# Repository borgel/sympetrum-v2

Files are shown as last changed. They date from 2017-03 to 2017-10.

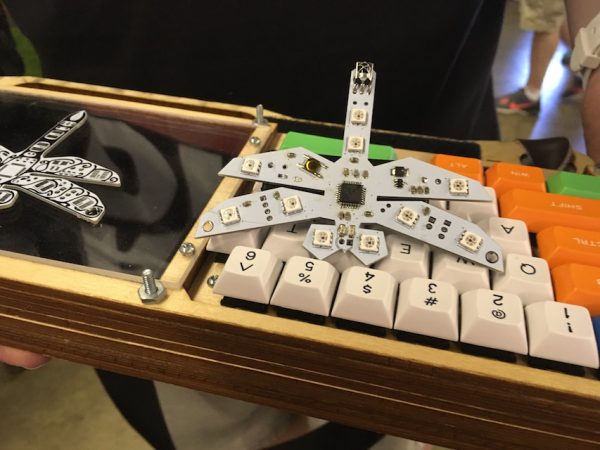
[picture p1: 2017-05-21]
Media/Adafruit commDeck_IMG_2102-600x450.jpeg

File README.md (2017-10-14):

# What?
An electronic conference badge, of course! (That makes this a wearable right?)

If you're interested in keeping up to date with new versions, you can add your email here: https://docs.google.com/forms/d/e/1FAIpQLSfi4PA6UNeILMCECjqM97Cd1tH6X2Ml2tzJlvIlYt14cOBuXQ/viewform. I'll start sending out info as we move towards DEFCON26.

## Yes, but what does it do?
By default the device does pleasant RGB fades across its 10 LEDs based on an internal clock. It also beacons that clock (and some other metadata) in infrared. They use any beacons they notice to synchronize their clocks, which also synchronizes the RGB patterns. The effect is that if one is alone, it plays random colors. If a group of them are together, they tend towards traversing the colorspace together.

For a little more information, it was kindly [written up by Hackaday here](https://hackaday.com/2017/07/14/badge-from-diamond-age-comes-to-def-con/).

This is a complete rewrite of the work done hastily in https://github.com/borgel/sympetrum for [DEFCON](https://defcon.org/) 24. The goal is to deploy at DEFCON 25 this year.

## Why is it a dragonfly?
If you haven't read Neal Stephenson's [_The Diamond Age: or, A Young Lady's Illustrated Primer_](http://www.goodreads.com/book/show/827.The_Diamond_Age), do that first. I'll wait.

If you have, there's a sequence around page 300 in which Miranda is first introduced to the possibility of using the drummers to find Nell. In this scene she attends a party in which the revellers wear colorful cloisonné dragonfly pins. As the party progresses they transition from random colorful flickering to some sort of synchrony, and Miranda notices the participants do the same. This is what I built.

A [_Sympetrum_](https://en.wikipedia.org/wiki/Sympetrum) is a genus of Dragonfly.

# How Do I Get One?
Unfortunately, I'm totally out. But everything is totally open source, so you can make one yourself! If you're interested check out [the Hardware Readme](Hardware/README.md) for recommendations.

The firmware used at DEFCON25 seems to work correctly and is considered "Final" barring bug discovery.

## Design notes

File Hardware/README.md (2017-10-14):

# Make One
If you're interested in making a Sympetrum badge, you're going to need two things: blank PCBs to assemble and the parts to assemble them with. Everything you'll need can be easily found on this project's [Kitnic page](https://kitnic.it/boards/github.com/borgel/sympetrum-v2/). 

## PCBs
Hit the button on the top of the Kitnic page that says "Download Gerbers". You'll get a zip file of the electrical files which describe the circuit board in a way that can be consumed by a fabrication house. There are a wide range of options for tuning these into circuit board you can use. Fab's I've purchased boards from and been happy include [PCBWay](https://www.pcbway.com), [Seeed Studio](https://www.seeedstudio.com/fusion_pcb.html) and [Dirty PCBs](https://dirtypcbs.com/store/pcbs). There are many other options. These boards are designed to fit in the common 100mm x 100mm size which is often heavily discounted. Expect these to cost around $25 (with shipping to the US!) for 10 in any color you want (they were designed for white solder mask / black silkscreen, the design should work correctly in any color).

### A Note on OSHPark
I love OSHPark and use them for all sorts of projects! Unfortunately for boards this large they are quite a bit more expensive than the Chinese options at around $60 for three boards. The quality will probably be higher but not likely in a meaningful way.

## Parts
The easiest way to order parts is again to use Kitnic. Below the images of the board there is a quantity selector and a Digikey button. If you press the button the webpage will magically open a Digikey card with all the parts in it (nifty isn't it?). At the time of writing it costs around $13 to build a single board from Digikey

If you'd rather do things the hard way you can directly upload the BOM to [Digikey](https://www.digikey.com/) or a tool like [Octopart](https://octopart.com/bom-tool) which will make it easy to order from a variety of suppliers.

### Caveats
* APA102C's, (AKA [DotStars on Adafruit](https://www.adafruit.com/product/2343)) may not be in stock on Digikey. If not, you can [buy them from Adafruit](https://www.adafruit.com/product/2343). You will need 10 for one dragonfly, though I recommend getting extra to fix ones that get damaged during assembly. They are also _much cheaper_ from EBay or Aliexpress, so consider those options if you're comfortable with them or  cost sensitive.
* The battery holder may not exactly fit the through holes on the PCB. They were custom sized to fit exactly the cheap holders I got on [Aliexpress](aliexpress.com). You could try lining one leg up and forcing the other to bend. Or use a holder with wires and gluing/taping it into place.

### Alternative Parts
Nothing in this design is particularly sensitive. If some specific part I selected is out of stock it should be safe to replace with a random part with the same parameters.

#### CPU
Sometimes the CPU seems to disappear from the common US suppliers. If this happens and you don't want to source from elsewhere the [STM32F051K8T6](https://www.digikey.com/product-detail/en/stmicroelectronics/STM32F051K8T6/497-13626-ND/3947378) can be swapped in place of the normal CPU. It's slightly fancier (AKA more expensive) and will require you to recompile the firmware for it, but that should be it.

To recompile the firmware for this CPU edit [the Makefile](/Firmware/Makefile) and swap the `CPU` variable by commenting out the line for `STM32F030x6` and in the one for `STM32F051x8`.

# Raw Sources
The final release gerbers are named `FF1.1` (formfactor 1.1) are [here](FF1.1). This is exactly what the Kitnic link mentioned above links to. This the final design which was used at DEFCON25.

The firmware is ["version 4"](https://github.com/borgel/sympetrum-v2/releases/tag/v4) and is tagged as a release on GitHub (and in [the Firmware directory](/Firmware)).

# Editiing/Contributing
If you want to make modifications, all design files made with [KiCAD](http://kicad-pcb.org/), a "Cross Platform and Open Source Electronics Design Automation Suite." It's very powerful, but has a steep learning curve.

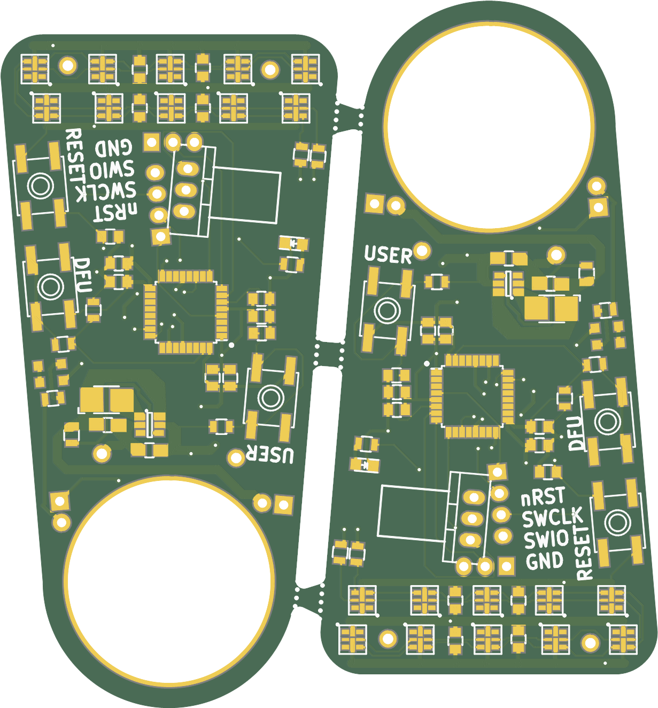
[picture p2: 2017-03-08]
Hardware/NFF1.1/gerbers-merged/merged-panel_Combined_Top.png

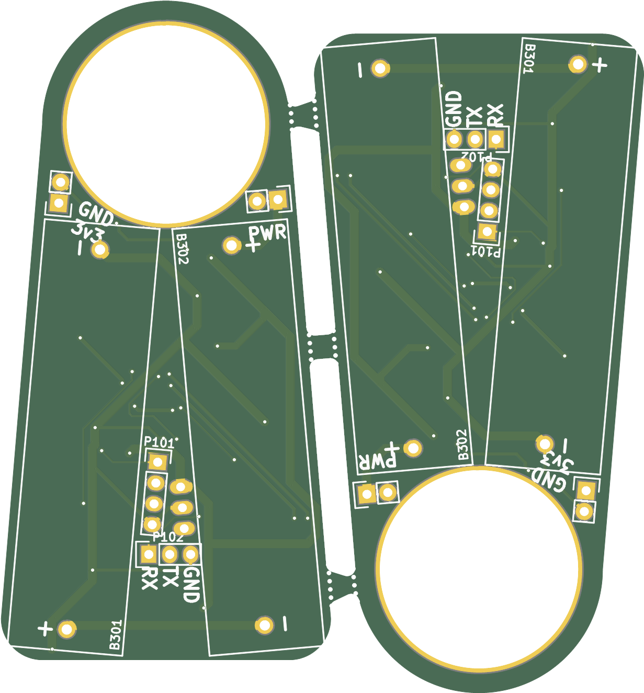
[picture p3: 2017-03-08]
Hardware/NFF1.1/gerbers-merged/merged-panel_Combined_Bottom.png

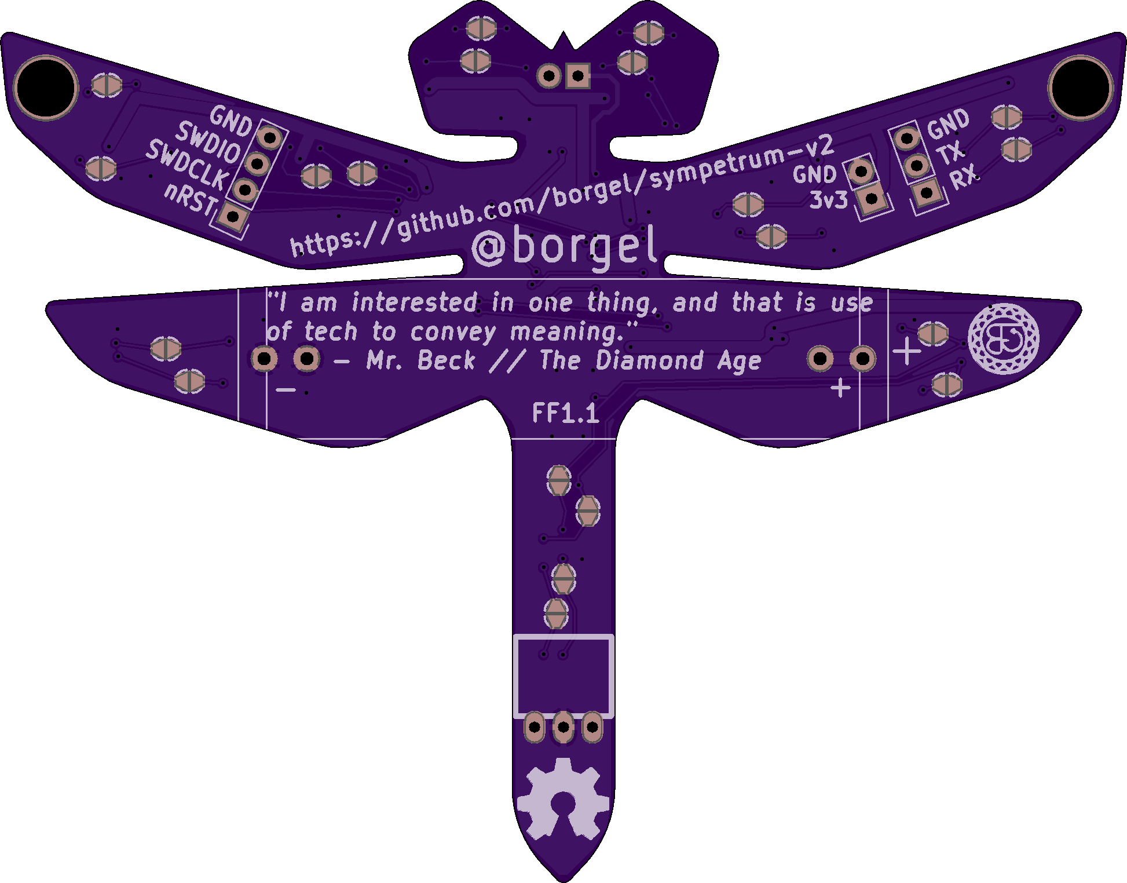
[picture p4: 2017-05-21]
Media/FF1.1 Back.png

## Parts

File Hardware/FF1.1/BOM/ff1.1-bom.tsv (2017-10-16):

References | Quantity | Description | PartNumber | DigiKey
U102 | 1 | TSSP58P38 | TSSP58P38 | TSSP58P38-ND
U101 | 1 | STM32F030K6T6 | STM32F030K6T6 | 497-14046-ND
U201;U202;U203;U204;U205;U206;U207;U208;U209;U210 | 1 | RGB LEDs | APA102C 5050 | 1528-1436-ND
B301 | 1 | AA Battery holder | BCAAPC | BCAAPC-ND
C101;C104;C105 | 3 | 0.1uF 0805 X7R |  | 478-3351-1-ND
C102 | 1 | 10nF 0805 X5R |  | 311-1136-1-ND
C103 | 1 | 1uF 0805 X5R |  | 1276-1246-1-ND
C202;C203;C201 | 3 | 22uF 0805 X5R |  | 1276-6460-1-ND
C106;C301;C302 | 3 | 4.7uF 0805 X5R |  | 1276-6465-1-ND
L301 | 1 | 4.7uH 0805 | LQH3NPN4R7NJ0L | 490-5346-1-ND
D102;D103 | 2 | IR25-21C/TR8 | IR25-21C/TR8 | 1080-1356-1-ND
R102 | 1 | 0R 0805 | RC0805JR-070RL | 311-0.0ARCT-ND
R101 | 1 | 10k 0805 |  | RMCF0805FT10K0CT-ND
R301 | 1 | 1M 0805 |  | RMCF0805JT1M00CT-ND
R103 | 1 | 36R 0805 |  | 311-36ARCT-ND
U301 | 1 | AAT1217-3.3 | AAT1217ICA-3.3-T1 | 863-1496-1-ND

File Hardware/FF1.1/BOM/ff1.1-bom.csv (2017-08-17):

Qty/Board | Line Item | Ref Des | Description | Manufacturer | MPN | DigiKey SKU | Distributor | Unit Price | Packaging | URL [Digi-Key]
1 | TSSP58P38 | U102 | TSSP58P38 | Vishay | TSSP58P38 | TSSP58P38-ND |  | 0.6615 | Bulk | https://octopart.com/click/track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
1 | STM32F030K6T6 | U101 | STM32F030K6T6 | STMicroelectronics | STM32F030K6T6 | 497-14046-ND |  | 1.0671 | Tray | https://octopart.com/click/track?country=US&ak=68b25f31&sig=009b28f&sid=459&ppid=30038872&ct=offers
10 | APA102C |  | RGB LEDs |  | APA102C 5050 | 1528-1436-ND |  |  | Bulk
1 | AA Holders |  | AA Battery holder |  | BCAAPC | BCAAPC-ND |  | 0.88 | Bulk | https://www.digikey.com/products/en?keywords=BCAAPC-ND%20
2 | 08055C104KAT2A | C104;C105 | 100nF |  | 08055C104KAT2A | 478-1395-1-ND | Digi-Key |  | Cut Tape
1 | 08055C104KAT2A | C101 | 0.1uF |  | 08055C104KAT2A | 478-1395-1-ND | Digi-Key |  | Cut Tape
1 | CC0805KRX7R9BB103 | C102 | 10nF | Yageo | CC0805KRX7R9BB103 | 311-1136-1-ND | Digi-Key | 0.0145 | Cut Tape | https://octopart.com/click/track?country=US&ak=68b25f31&sig=04411b9&sid=459&ppid=192989&ct=offers
1 | CC0805KKX7R7BB105 | C103 | 1uF | Yageo | CC0805KKX7R7BB105 | 311-1365-1-ND | Digi-Key | 0.0325 | Cut Tape | https://octopart.com/click/track?country=US&ak=68b25f31&sig=0ad85ca&sid=459&ppid=8376555&ct=offers
3 | CL21A226MQQNNNG | C202;C203;C201 | 22uF | Samsung | CL21A226MQQNNNG | 1276-6460-1-ND | Digi-Key |  | Cut Tape
3 | CL21F475ZPFNNNE | C106;C301;C302 | 4.7uF | Samsung | CL21F475ZPFNNNE | 1276-3022-1-ND | Digi-Key |  | Cut Tape | https://www.digikey.com/product-detail/en/samsung-electro-mechanics-america-inc/CL21F475ZPFNNNE/1276-3022-1-ND/3891108
1 | LQH3NPN4R7NJ0L | L301 | 4.7uH | Murata | LQH3NPN4R7NJ0L | 490-5346-1-ND | Digi-Key | 0.2646 | Cut Tape | https://octopart.com/click/track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
2 | IR25-21C/TR8 | D102;D103 | IR25-21C/TR8 | Everlight | IR25-21C/TR8 | 1080-1356-1-ND | Digi-Key | 0.1797 | Cut Tape | https://octopart.com/click/track?country=US&ak=68b25f31&sig=0198f6b&sid=459&ppid=17677898&ct=offers
1 | RC0805JR-070RL | R102 | 0R | Yageo | RC0805JR-070RL | 311-0.0ARCT-ND | Digi-Key | 0.0072 | Cut Tape | https://octopart.com/click/track?country=US&ak=68b25f31&sig=0bc70cf&sid=459&ppid=55402891&ct=offers
1 | RC0805JR-0710KL | R101 | 10k | Yageo | RC0805JR-0710KL | 311-10KARCT-ND | Digi-Key |  | Cut Tape
1 | RC0805FR-071ML | R301 | 1M | Yageo | RC0805FR-071ML | 311-1.00MCRCT-ND | Digi-Key | 0.0077 | Cut Tape | https://octopart.com/click/track?country=US&ak=68b25f31&sig=00e7688&sid=459&ppid=39987041&ct=offers
1 | RC0805FR-0736RL | R103 | 36R | Yageo | RC0805FR-0736RL | 311-36.0CRCT-ND | Digi-Key | 0.0077 | Cut Tape | https://octopart.com/click/track?country=US&ak=68b25f31&sig=09cc5c1&sid=459&ppid=1165961&ct=offers
1 | AAT1217ICA-3.3-T1 | U301 | AAT1217-3.3 | Skyworks Solutions | AAT1217ICA-3.3-T1 | 863-1496-1-ND | Digi-Key | 0.6774 | Cut Tape | https://octopart.com/click/track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

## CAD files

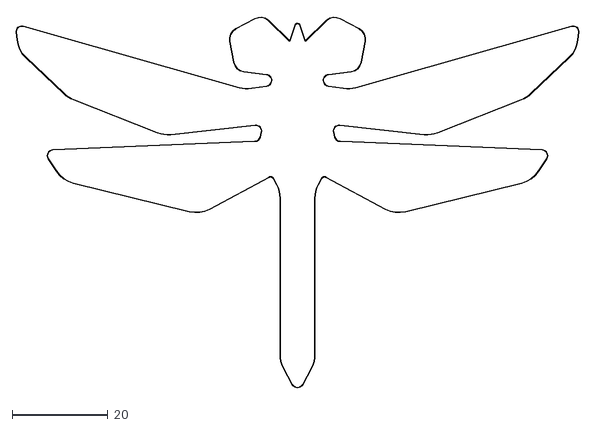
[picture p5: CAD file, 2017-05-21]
Hardware/FF1.1/Outline/Outline-Rounded-Libre-R12-v1 (Smaller).dxf
117.6 x 77.6

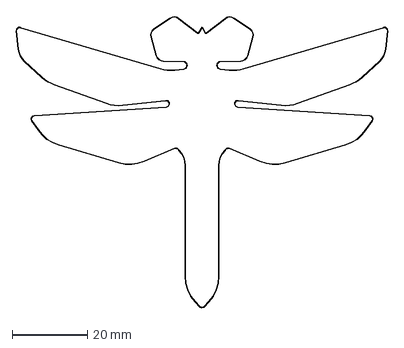
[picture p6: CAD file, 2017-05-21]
Hardware/FF1.1/Outline/Outline-Rounded-Libre.dxf
98.8 x 77.5 mm

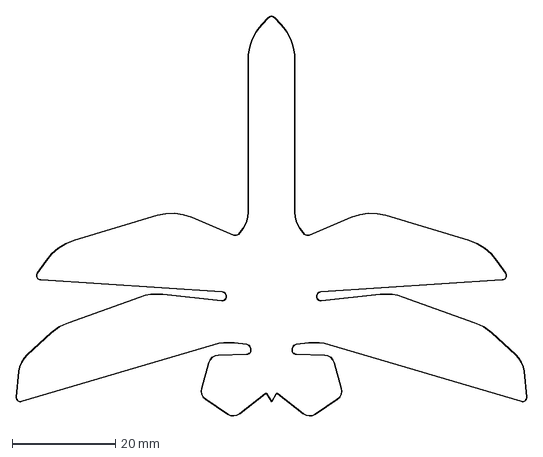
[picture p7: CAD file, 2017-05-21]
Hardware/FF1.1/Outline/Outline-Rounded-Fusion.dxf
98.8 x 77.5 mm

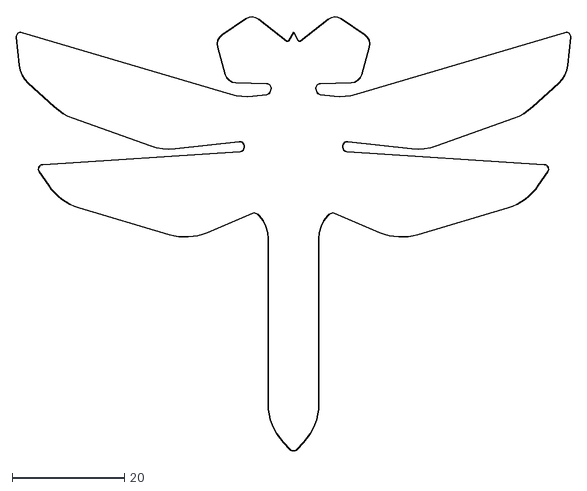
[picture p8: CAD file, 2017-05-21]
Hardware/FF1.1/Outline/Outline-Rounded-Libre-R12.dxf
98.8 x 77.5

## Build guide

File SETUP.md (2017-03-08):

# OSX
## CubeMX

A very handy GUI tool for confguring peripherals, clocktrees, etc. Can generate init code. Figuring out how to init peripherals in ST land can be _murderous_, so I recommend trying to use the tool.

1. Download [STM32 Cube MX](http://www.st.com/content/st_com/en/products/development-tools/software-development-tools/stm32-software-development-tools/stm32-configurators-and-code-generators/st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) from ST.

2. Install it. This will REQURE a version of the JRE and JDK (1.8 at time of writing). You MUST install these from the Oracle website [1] before the CubeMX installer will run.

3. Run the CubeMX installer. By default it installs a `/Applications/STMicroelectronics/STM32CubeMX.app`.

4. Run CubeMX and start a new project to configure a board.

5. When running the code generator, you will be asked to choose a toolchain. Unfortunately none of the options are "gcc" or similar. I've heard it recommended to select TrueStudio to generate our linker script for us. We will also need to manually construct a `makefile`.

### Notes

* The first time you run the code generator, it will notice you're missing the STM32Cube libraries themselves and offer to download them. Do this.
* There is a tool to generate Makefiles from CubeMX projects [6], but I was unable to get it to work. (However I did end up using their makefile as a template).

## Toolchain

1. Install the latest GNU Embedded Toolchain with `brew cask install gcc-arm-embedded`

2. Alternativel install latest GNU Embedded Toolchain for ARM from [3]. One recommendation for this is to do

```
$ mkdir -p /usr/local
$ cd /usr/local
$ sudo tar xjf ~/Downloads/gcc-arm-none-eabi-4_9-2015q3-20150921-mac.tar.bz2
```

3. Install the programming tools via Homebrew (or from source[4]) `brew install stlink`. A small tutorial for using these tools to flash a board is at [5].

## Building

1. TODO explain how to adapt my Makefile.

## Flashing

1. TODO. Explain how to call `st-flash write FILENAME.bin 0x8000000` and what each param means.

# Other Platforms

For Windows and Linux, apparently there is now a free (not open source?) Eclipse-based IDE for STM32 [2].

[1] http://www.oracle.com/technetwork/java/javase/downloads/jdk8-downloads-2133151.html http://www.oracle.com/technetwork/java/javase/downloads/jre8-downloads-2133155.html
[2] http://www.st.com/en/development-tools/sw4stm32.html http://www.openstm32.org/HomePage
[3] https://developer.arm.com/open-source/gnu-toolchain/gnu-rm/downloads
[4] https://github.com/texane/stlink
[5] https://github.com/texane/stlink/blob/master/doc/tutorial.md
[6] https://github.com/baoshi/CubeMX2Makefile

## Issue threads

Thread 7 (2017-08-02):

Generic Parts Listed

gh0stshell, 2017-08-02:
I need help identifying the parts listed as generic on your BOM located at

https://upverter.com/borgel/748d5ee8f0eb00f8/sympetrum-v02/

I dont know what parts I need to get

borgel, 2017-08-03:
Hmm, you might not want to build that version. It's harder to assemble and the FW never worked quite right. If you're trying to make the version from this year you want the files in the 'Hardware/FF1.1" directory in this repo. I'm still putting together a BOM to make it easy to buy parts though (hopefully done in the next few days).

gh0stshell, 2017-08-03:
What is the dimensions? One site I am getting a price for the board requires PCB Dimension.

borgel, 2017-08-04:
Boards are slightly less than 10cm x 10cm (if you're ordering from a place with size buckets).

Not sure if it's helpful yet, but I got a basic BOM up https://github.com/borgel/sympetrum-v2/tree/master/Hardware/FF1.1/BOM

gh0stshell, 2017-08-04:
Looks good, no generic parts listed

gh0stshell, 2017-08-05:
Having an issue with this components

CL21A106KQCLRNC

Would either of this work as a alt?

CC0402KRX5R6BB104

SMD CAP Ceramic 100nF-10V-10%-X5R

gh0stshell, 2017-08-05:
Actually the part on the sheet CL21A106KQCLRNC lists 100nF, but when you check the link it lists

CAP CER 10UF 6.3V X5R 0805

So how about this one?

CC0402MRX5R5BB106

gh0stshell, 2017-08-05:
Also for the APA102C

How about this one? WS2812B Adafruit is sold out of the APA102C atm

borgel, 2017-08-06:
Will check the passives when I get home. This design isn't very sensitive to tolerance and whatnot. As generally anything with the right value and the right size (everything is 0805) it should work.

Unfortunately you definitely cannot substitute the LEDs. The WS2812Bs communicate in a different way (and have 2 fewer pins!) So they won't work at all. However you can get APA102Cs from eBay and AliExpress pretty easily (usually much cheaper). You can also get non RGB versions which should work correctly, but obviously won't be color.

gh0stshell, 2017-08-06:
Ya I stuck with the listed LEDs and was able to find them even though adafruit was out of stock and bought some

gh0stshell, 2017-08-14:
7 and 11 show same PN, but difference decscrptions and price, I already started a full run of built units and boards, if I ordered the wrong parts per the links for 7 and 11 I can live with that, if the listings are wrong it will cost more of the pre-built units current being made

gh0stshell, 2017-08-14:
7 and 11 also show the same SKU as well

borgel, 2017-08-15:
Aww darn, no those should have different part numbers. Going to have to flog KiCAD and figure out what it should actually be. The value in the `Description` field looks like it's correct, so it's just the part number.

borgel, 2017-08-15:
Ok. It was actually supposed to be another `CL21A106KQCLRNC` like line 6 (yes, I labeled components with the same value in different units. Need to fix that too, but haven't changed the schematics to match it).

gh0stshell, 2017-08-15:
So what all is wrong now? This means the fully built boards have 3 wrong parts and I ordered incorrect parts and did not order.

borgel, 2017-08-16:
Crap. Well, it looks like 11 is still wrong. So so far my two errors look like lines 7 and 11.

7: Installing a different capacitor for 7 shouldn't matter (it just debounces the reset line. A bigger or smaller cap likely won't change anything).
11: This actually needs to be correct, and it looks like I have the wrong part number here too. I updated the BOM with the right part.

So it seems like just 11 needs to be fixed.

Sigh, I'm really sorry about this. I'm not sure at what step this got garbled... It's possible this happened earlier and I produced some amount of units with these errors

gh0stshell, 2017-08-16:
Actually no need to be sorry as I just got a response from the company and they have not gone to assembly yet so I have time send a correct BOM or what needs to be correct, if you could do that I it would be awesome

gh0stshell, 2017-08-16:
i see there is a new BOM, is that a correct one I can send for assembly?

borgel, 2017-08-17:
Awesome! Glad that was in time.

It's correct as far as I know, but I was wrong before... I'm still at work, but so far it looks like all the values in `Description` have been correct so far, but the part numbers haven't been. If you search for each part number and validate that it matches the `Description` that should catch anything left that's incorrect.

Out of curiosity, who are you having make/assemble the boards? What prices are you seeing? If you don't mind sharing.

borgel, 2017-08-17:
Turned out I had a little time. This is what I see wrong:
- It looks like `CL21A106KQCLRNC` is still wrong and matches neither line 6 or 7.
- 10 (CL21F105ZOFNNNE) is wrong
- 15 (RC0805JR-071KL) is wrong

All those have correct values... but not for that line. I wonder if somehow there was a bizarre reordering or something

Try making:
6: 08055C104KAT2A (DigiKey 478-1395-1-ND)
7: 08055C104KAT2A (DigiKey 478-1395-1-ND)
10: CL21A226MQQNNNG (DigiKey 1276-6460-1-ND)
15: RC0805JR-0710KL (DigiKey 311-10KARCT-ND)

borgel, 2017-08-17:
Ok, I updated the BOM again. I've now checked everything manually against its `Description` field and believe it all to be correct.

gh0stshell, 2017-08-17:
OK I will download it again and send it off before I run out of time, thank you very much

gh0stshell, 2017-08-19:
bad news, 6 and 7 are now the same

borgel, 2017-08-19:
I think that's actually correct. I accidentally named C101 using a different unit from C104 and C105.

gh0stshell, 2017-08-19:
whew!

Could provide a file where is shows what parts go where(numbers on board to match BOM Ref Des) like the ones you just mentioned, it only shows the LED numbers on the board thanks in advance!

gh0stshell, 2017-08-19:
I also got just the board made an are ordering parts but dont know where to put them

gh0stshell, 2017-08-19:
also if you could give me a guide to flash the firmware I would appreciate it

gh0stshell, 2017-08-22:
So I figured out where the LEDs go and the ST chip, but no idea where the other parts go

borgel, 2017-08-23:
Sorry, was out of town and not doing much computing

I added a new document called `sympetrum-v2 FF1.1-F.Fab.pdf` to the HW/FF1.1 directory. It shows where each component goes.

There are two ways to flash the firmware.
1) Use an SWD programmer (like an ST-LINK/V2, or a Segger JLink, or a Bus Pirate, or others) and connect to the 4 pin programming header. If you need to get a programmer the cheapest option is probably to get one of the skeezy cheap ST-LINK/V2 Mini clones like [0]. I used one (from another source) for most of my development and it was fine.
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
gh0stshell, 2017-08-26:
Question, i am finishing up my board and last piece i am doing is the IR recv on the tail, it looks like the spot for it is on the back of the board, shouldn't be on the front so it talks to the other badges I will eventually have so the LEDs sync?

borgel, 2017-08-26:
Hmm, it should be on the top. There isn't really much on the silkscreen besides a vertical line underneath where the body sits at the veeeeeery end of the tail.

If you insert it's legs through the top then fold it down with the window having outward that should work.

borgel, 2017-08-26:
Do you mind sending a photo when you finish? I'd love to see how it turned out. It's kind of blowing my mind that someone else made one!

gh0stshell, 2017-08-27:
Ya sure, I just have to do the main chip, batt, and IR, I ask about the IR as there is a spot on back that is a square looking like where it sits

gh0stshell, 2017-08-27:
tip I will be using I learned from the DC Darknet badge, pliers to bend the IR, makes a perfect 90 degree angle and lays flush on the board

gh0stshell, 2017-08-27:
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

I have enough to make 9 more

jthoel, 2017-08-27:
Nice work!  I've been following along the conversation. I picked up a
broken one at DefCon and am trying to repair it.  I'm going to order leds
(i got the wrong ones earlier) and then test the board.  Great to see it
working!

On Sat, Aug 26, 2017 at 8:45 PM, gh0stshell <notifications@github.com>
wrote:

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

gh0stshell, 2017-08-27:
I ordered boards then ordered all the parts, i made this from scratch

gh0stshell, 2017-08-27:
here is a better pic from the maker

https://lh6.googleusercontent.com/Apjwzfcd5rGi5Dd5XBWZZPZ3DFGu11GQ79bOFPmc_ytsunu4enYdPfqG0VfeWvRQLmdTbMKzPg=w2620

borgel, 2017-08-27:
Oh, I see what happened @gh0stshell ! That little box is where I hand wrote the serial numbers! Should probably have considered that it wasn't clear what it was actually _for_.

Awesome! Looks great!

Holler if you have any questions @jthoel !

gh0stshell, 2017-08-27:
I want to change the colors so I can use a different board color then white, what would I need to do that?

WildSamosa, 2017-08-27:
@gh0stshell I was able to order PCBs in white with black silkscreen, and black with white silkscreen.  I used the same files for both orders and they came out great.  Waiting for parts from the updated BOM before I can assemble it.  Yours looks fantastic!  Did you have anything pick and placed, or is that all hand soldered?
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

gh0stshell, 2017-08-27:
i think we know each other on discord, only one part changed on the BOM recently and I made one before I got it and so did another that went in with me and it works without the one new part

gh0stshell, 2017-08-27:
#2 just was completed so now I now I can see them sync

gh0stshell, 2017-08-27:
@WildSamosa, i am building them all by hand, no assembly

gh0stshell, 2017-08-27:
and number 3 is done, soon i will have enough to hang from my ceiling, learned a good trick and which tip to use for the chip that also seems to work well with all the other parts, more precise

gh0stshell, 2017-09-07:
@WildSamosa, could I buy some black boards off you? I have other colors coming, but not black.

gh0stshell, 2017-09-07:
@borgel, how can I donate to you?

borgel, 2017-09-09:
Haha, no donations required. That's why it's open source! Just learn from it and put the knowledge to use!

gh0stshell, 2017-09-14:
So I have been playing with the first 2 I made, 3rd I have some programming issues most likely due to bridged pins, but with the working 2 I have hung them from the ceiling pointed at each other and waiting for them to sync and they never do so could you give me a run down of what to expect?

borgel, 2017-09-20:
Cool!

So when each one is powered on, they should do a random RGB fade across all the LEDs. When a few of them are "near" each other (with no obstructions or other sources of modulated IR I'd think the range would be pretty far. 10 feet maybe? 15?) they will slowly switch from a random fade to a cycle through the RGB spectrum.

With the values in the last version of the firmware, two boards will appear to be partially random and partially "synced", and three boards will look nearly totally synced and not random at all. The more frequently they see a beacon from another board the less random they appear to be. It will likely take minutes for them to all line up. It's... a little hard to explain in text.

All this code lives in `pattern.c` [1]. To make two look fully synced instead of partially random, adjust the values in the array `BiasWeightRamp` in `pattern.c` so that each value is 90 or 100 (100 is the maximum).

[1] https://github.com/borgel/sympetrum-v2/blob/master/Firmware/Src/pattern.c

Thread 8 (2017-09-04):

Possibly missing libraries?

dodohand, 2017-09-04:
Opening sympetrum-v2 FF1.1.pro with KiCad 4.0.7-e2-6376-58-ubuntu14.04.1 and
I get errors that these two libraries weren't found:

"/Users/borgel/Dropbox/kicad/Libraries/Borgel Custom"
and
"/Users/borgel/Dropbox (Personal)/kicad/Libraries/Borgel Custom"

... and am then left with quite a mess of a schematic with lots of missing symbols.
Would it be possible for you to create a library of the symbols you've created for
this schematic and add it to this repo? (assuming this issues repeats for you when
you try it out on another machine without your Dropbox libraries?

gh0stshell, 2017-09-07:
looks like a known issue with linux and KiCad

Source: https://lists.launchpad.net/kicad-developers/msg25255.html
Repo Needed: sudo add-apt-repository --yes ppa:js-reynaud/kicad-4

I installed that version instead of the default on in the repo and no errors for me at least

gh0stshell, 2017-09-07:
Tried on my Win10 which looks like what is listed in your error and no errors out of the box for me at least

gh0stshell, 2017-09-07:
On the KiCad web site download section the PPA listed in the source I posted is also listed there under the ubuntu section

http://kicad-pcb.org/download/ubuntu/

borgel, 2017-09-07:
Thanks for catching that @dodohand ! (and for the help @gh0stshell ). It looks like I was missing a file.

I think my `.gitignore` quietly left off `sympetrum-v2 FF1.1-cache.lib`, which should be the library cache of all the symbols and things for the schematic. I just added it to `master`. Does it work now?

gh0stshell, 2017-09-07:
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

gh0stshell, 2017-09-07:
For me it keeps asking for 3 schem files, 2 you have posted, trying to see what the other one is

gh0stshell, 2017-09-07:
In Windows after adding .lib file I now get this when opening the schem file

The following libraries were not found:
sympetrum-v2 FF1.1-rescue
sympetrum-v2 FF1-rescue
\Users\borgel\Dropbox\kicad\Libraries\Borgel Custom
\Users\borgel\Dropbox (Personal)\kicad\Libraries\Borgel Custom

gh0stshell, 2017-09-07:
BUT it looks ok, i guess, im new to this so you guys tell me

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

gh0stshell, 2017-09-07:
So me wanting to not leave it alone, I copied sympetrum-v2 FF1.1-cache.lib, and made two copies named

sympetrum-v2 FF1.1-rescue.lib
sympetrum-v2 FF1-rescue.lib

And no oddness and those errors went away and now have these left

The following libraries were not found:
\Users\borgel\Dropbox\kicad\Libraries\Borgel Custom
\Users\borgel\Dropbox (Personal)\kicad\Libraries\Borgel Custom

dodohand, 2017-09-08:
I now get the same results as gh0stshell - namely that the schematic is now complete, but the footprints are unavailable. This means that while I can now, for example, correctly make a copy of U210 as U211 in order to add an 11th LED to the schematic, I cannot successfully import that netlist into Pcbnew because the footprint from ."../Libraries/Borgel Custom" is not available.  While I could create my own footprint, I think that you intended it to be self-contained, and it isn't yet.

borgel, 2017-09-09:
I'm really sorry about that, definitely still figuring out the best way to package all this up.

Based on [1], I archived all the footprints in the `.kicad_pcb`, then added that local footprint library to the project specific search path, then push it all up. Hopefully if you pull fresh from `master` it should work now.

[1] https://hackaday.com/2017/05/18/kicad-best-practises-library-management/

gh0stshell, 2017-09-10:
Tried on Windows this time, download the entire master, extracted it to a new folder, opened KiCad and pointed it to that folder and opened the pro file and when open sch

The following libraries were not found:
sympetrum-v2 FF1-rescue
\Users\borgel\Dropbox\kicad\Libraries\Borgel Custom
\Users\borgel\Dropbox (Personal)\kicad\Libraries\Borgel Custom

gh0stshell, 2017-09-10:
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

dodohand, 2017-09-26:
as gh0stshell demonstrated, the schematic now loads properly, and the footprints can be extracted from the pcb layout, so I'm going to close this.

Closed 2017-09-26.

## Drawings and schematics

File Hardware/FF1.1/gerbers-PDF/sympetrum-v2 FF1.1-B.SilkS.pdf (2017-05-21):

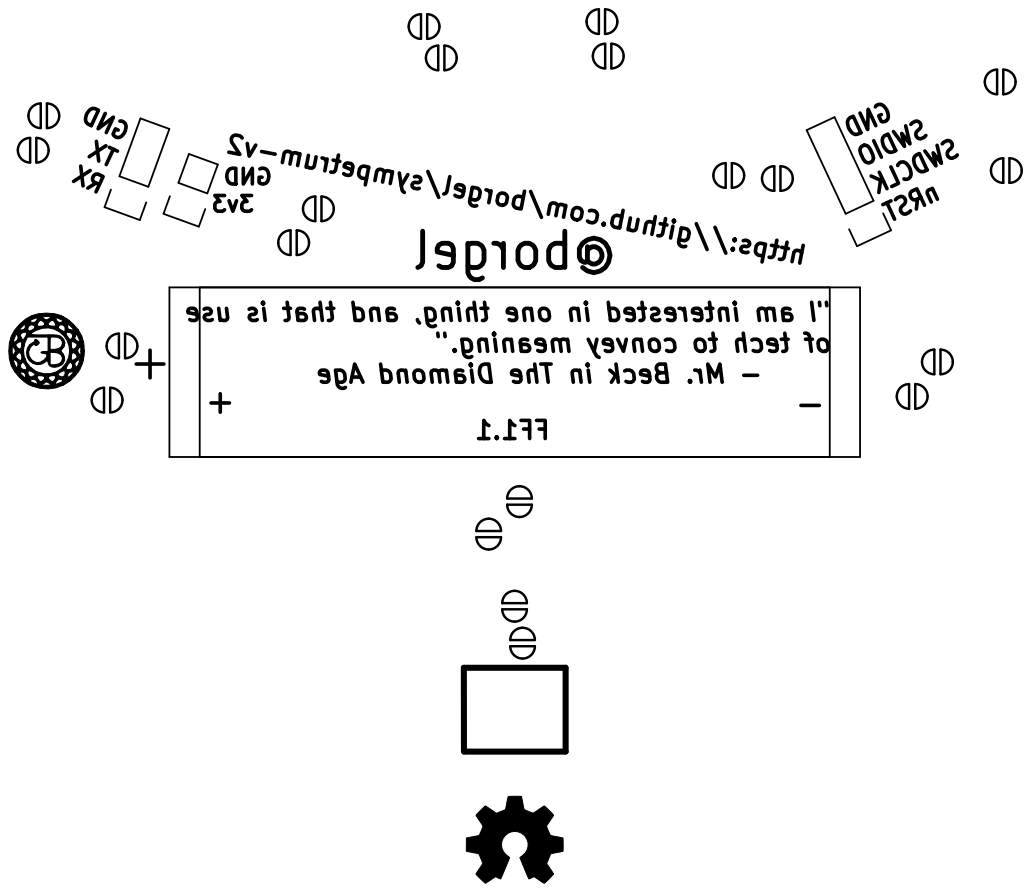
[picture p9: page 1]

GND TXRX https://github.com/borgel/sympetrum-v2

GND SWDIO SWDCLK nRST GND 3v3

"I am interested in one thing, and that is use

of tech to convey meaning." + - Mr. Beck in The Diamond Age

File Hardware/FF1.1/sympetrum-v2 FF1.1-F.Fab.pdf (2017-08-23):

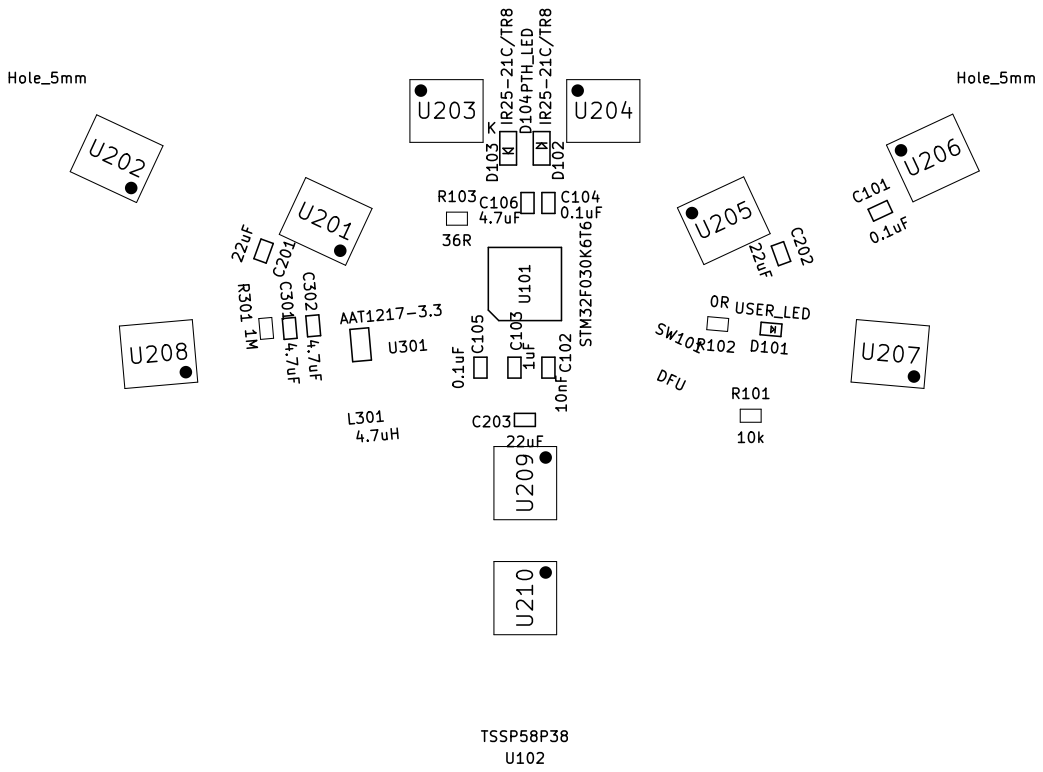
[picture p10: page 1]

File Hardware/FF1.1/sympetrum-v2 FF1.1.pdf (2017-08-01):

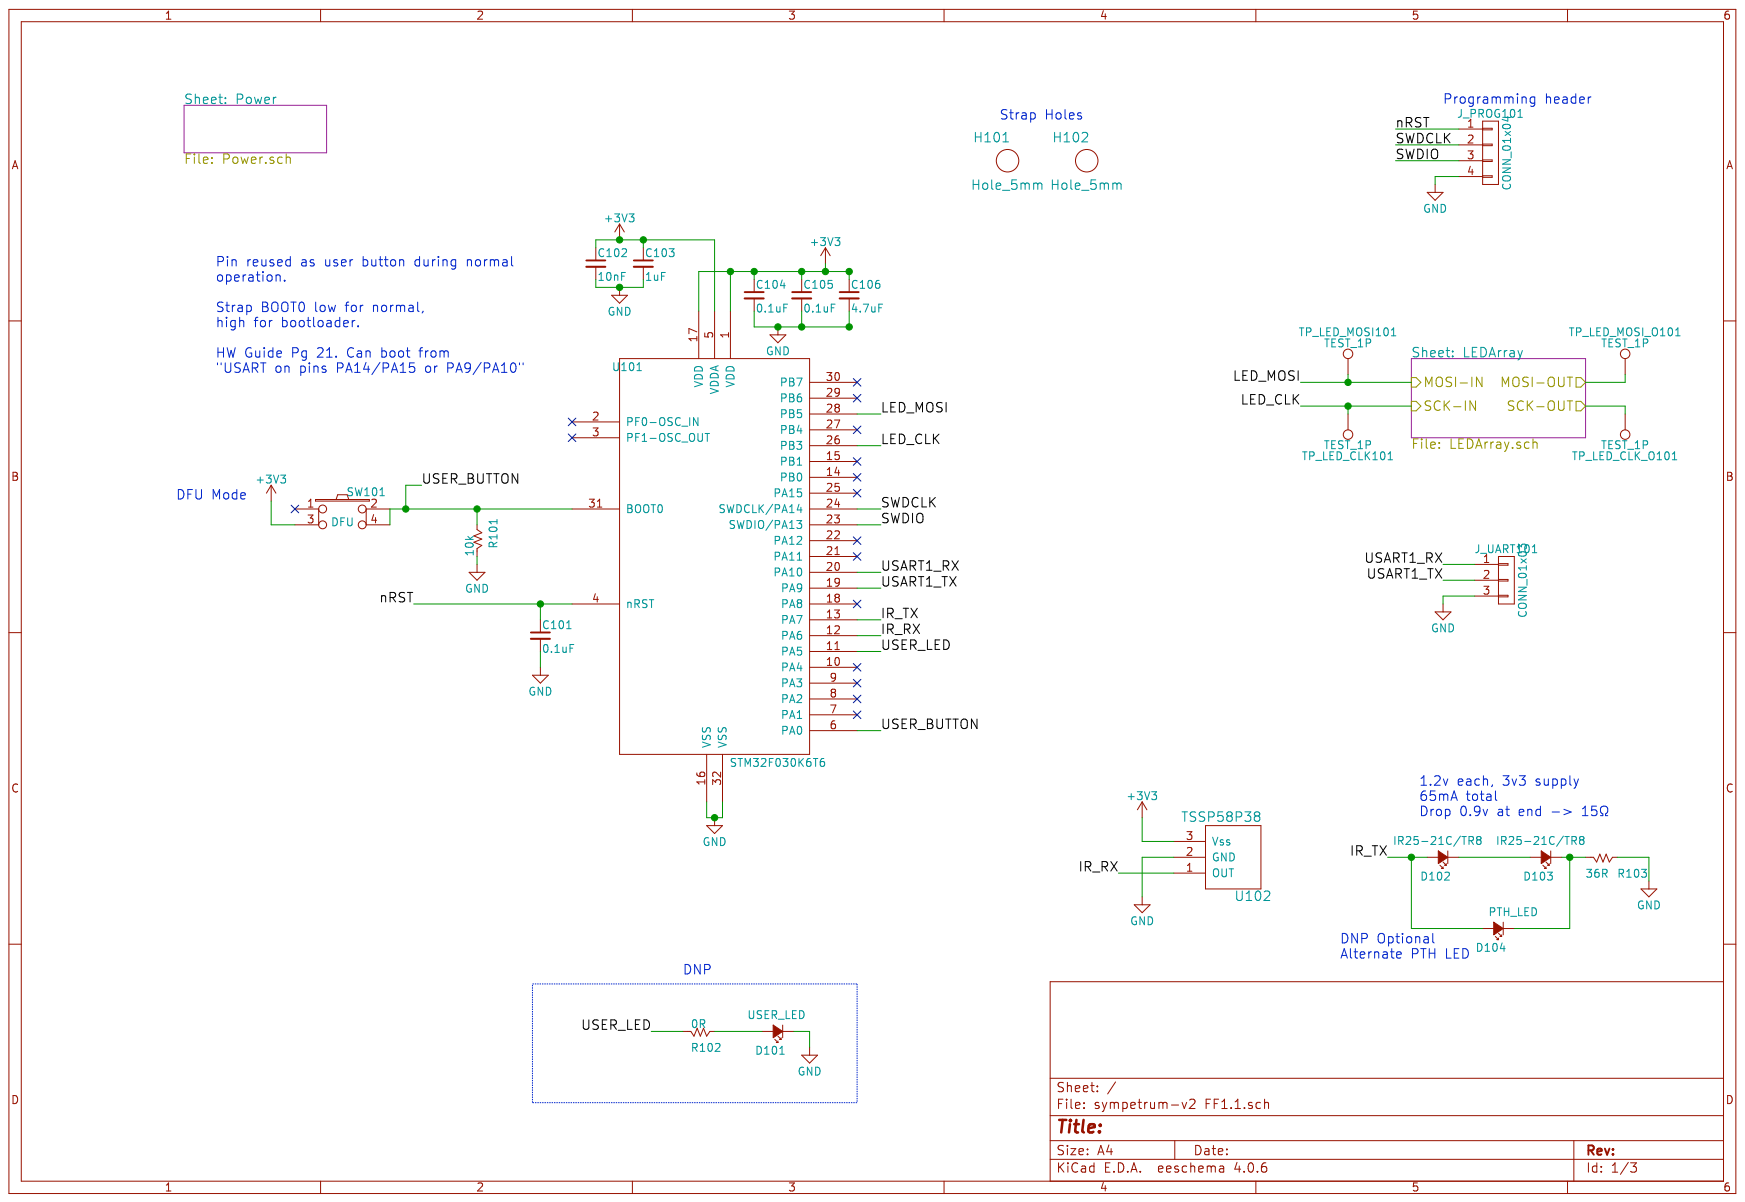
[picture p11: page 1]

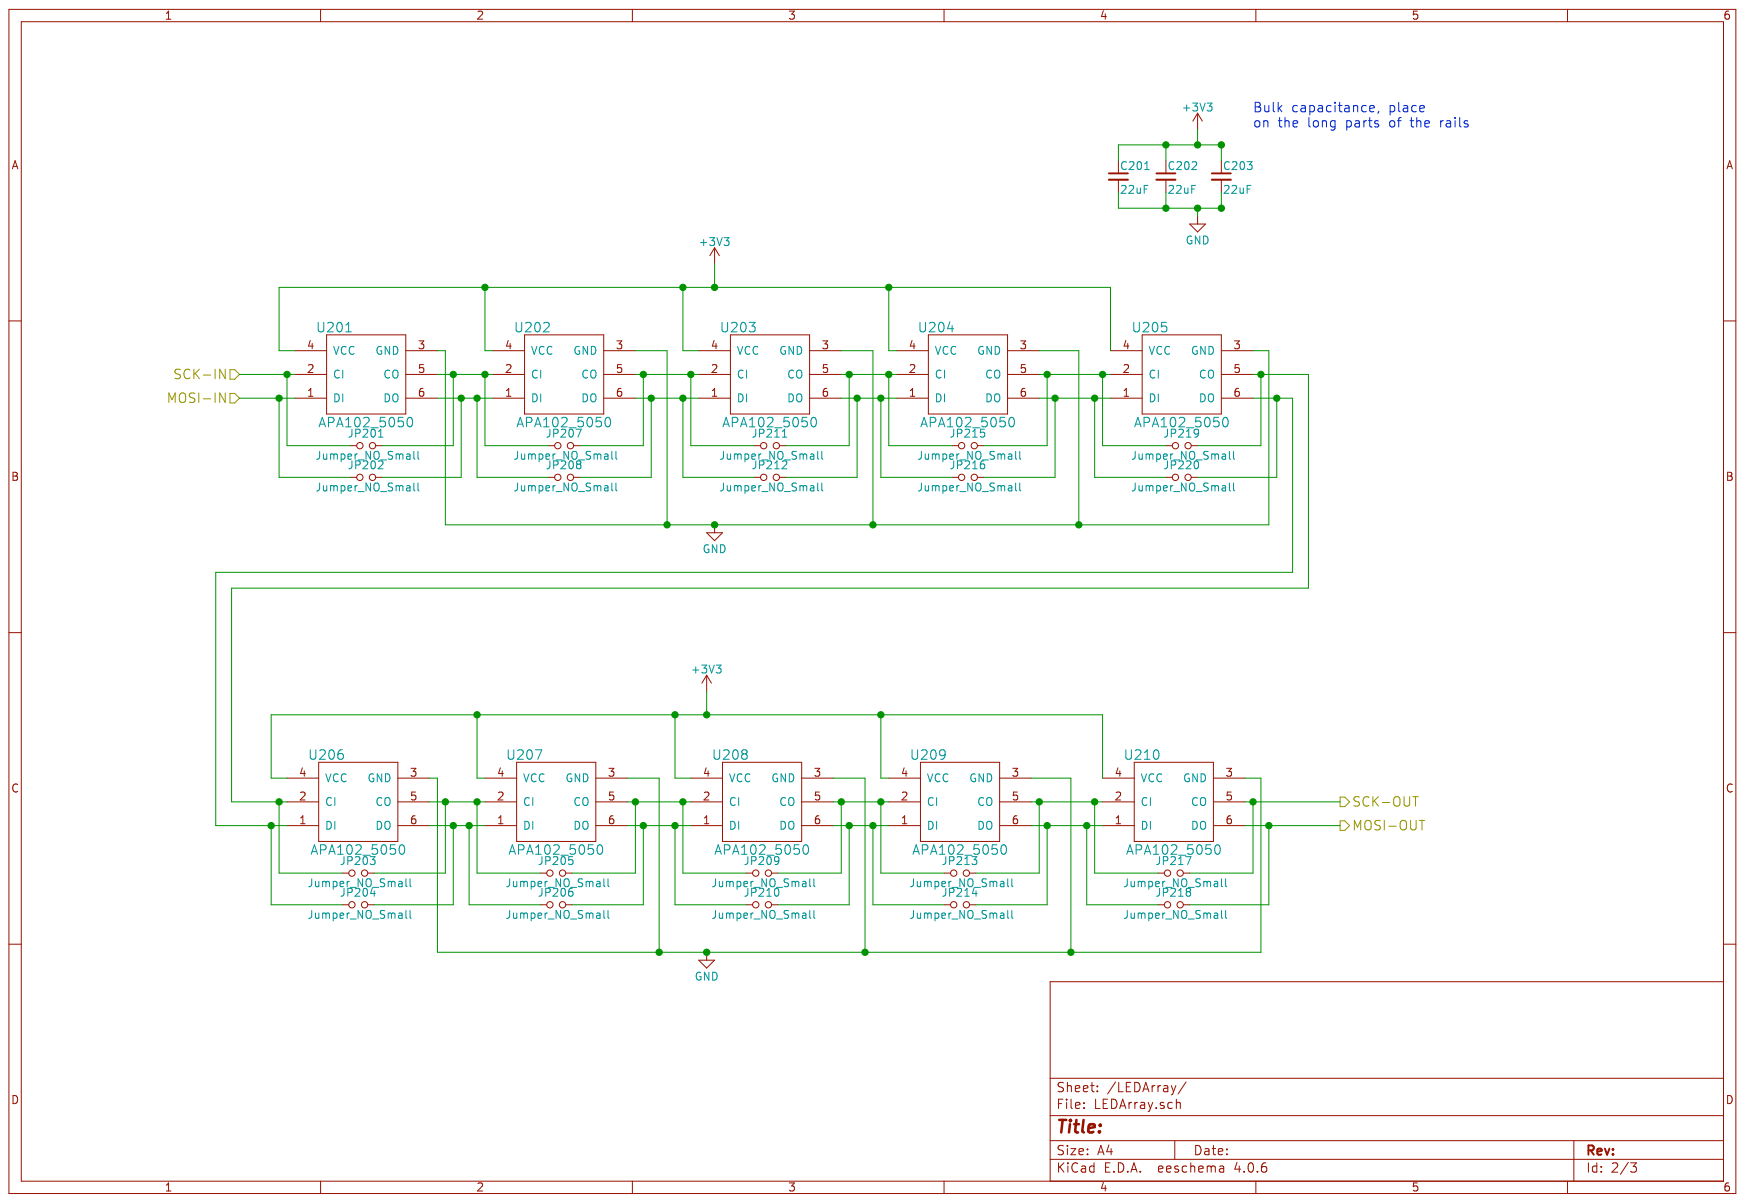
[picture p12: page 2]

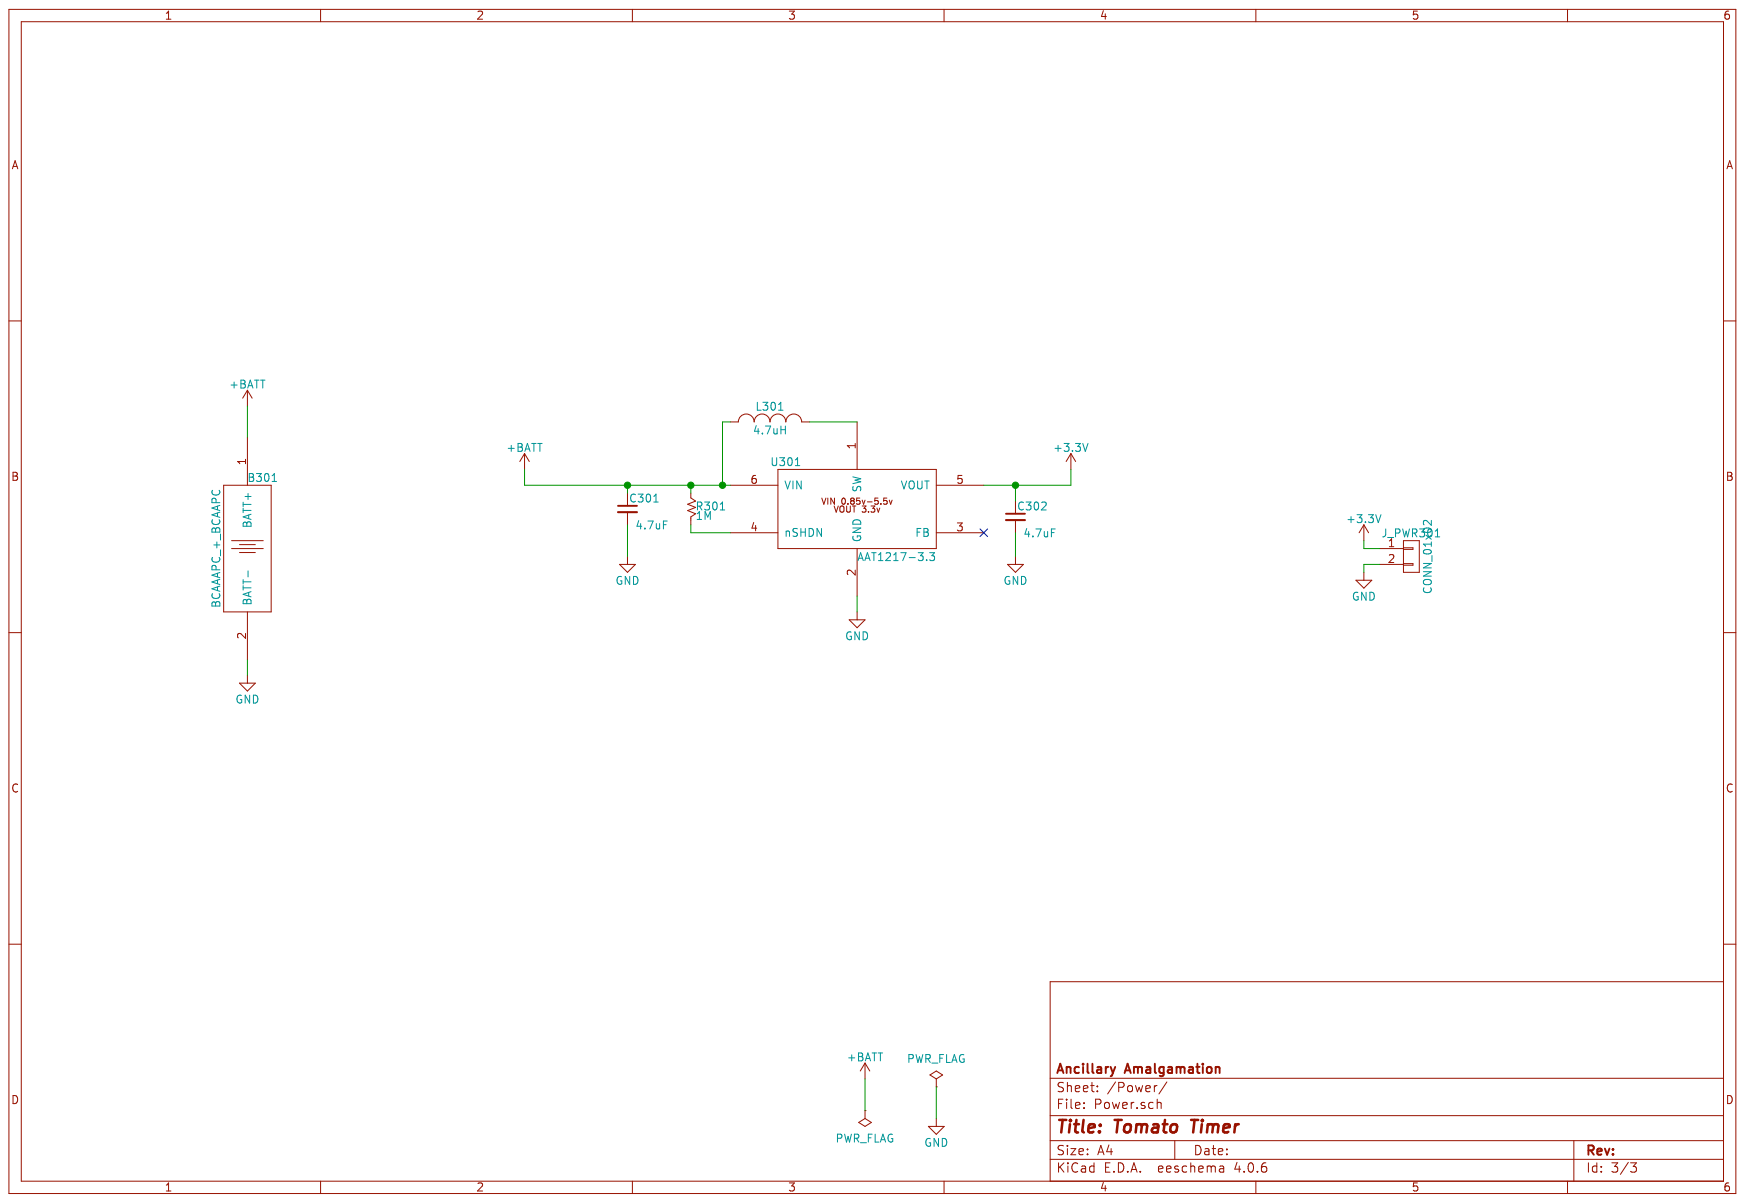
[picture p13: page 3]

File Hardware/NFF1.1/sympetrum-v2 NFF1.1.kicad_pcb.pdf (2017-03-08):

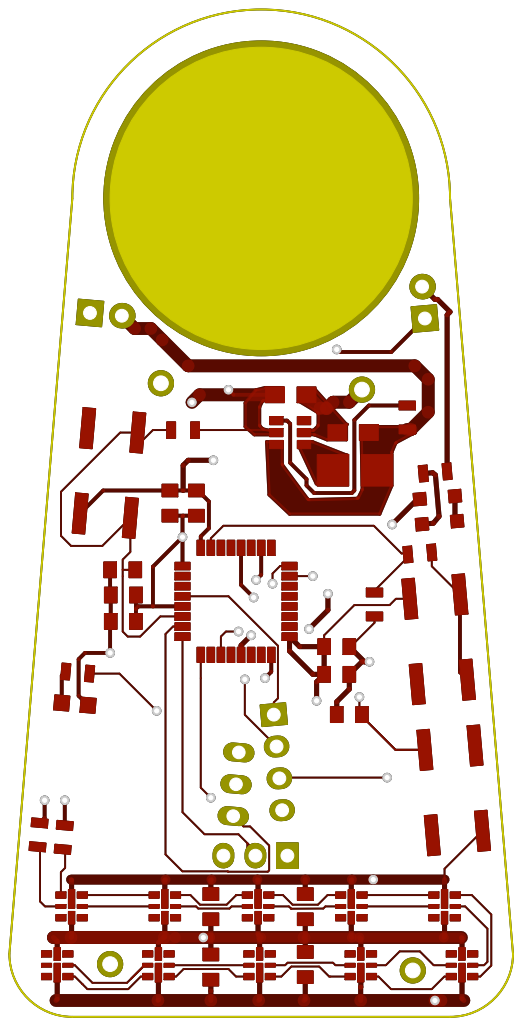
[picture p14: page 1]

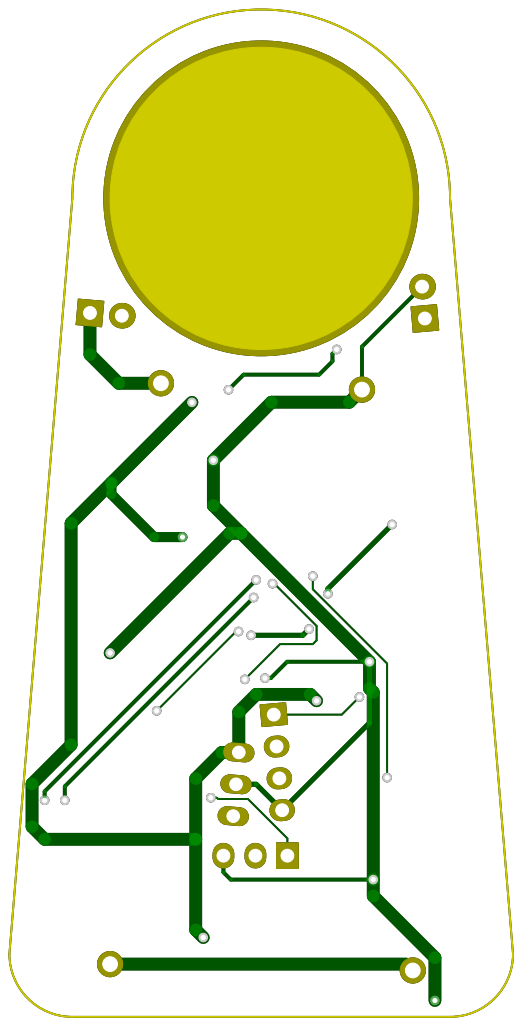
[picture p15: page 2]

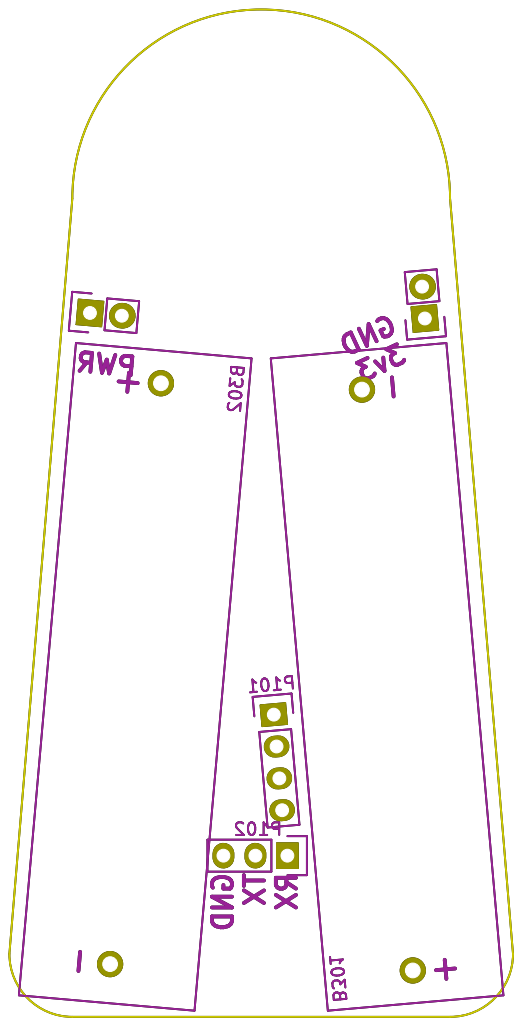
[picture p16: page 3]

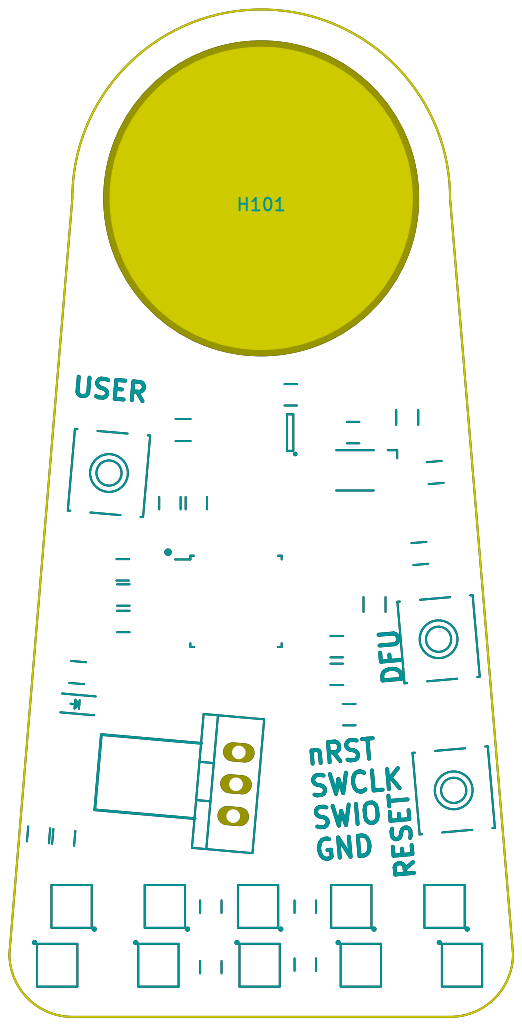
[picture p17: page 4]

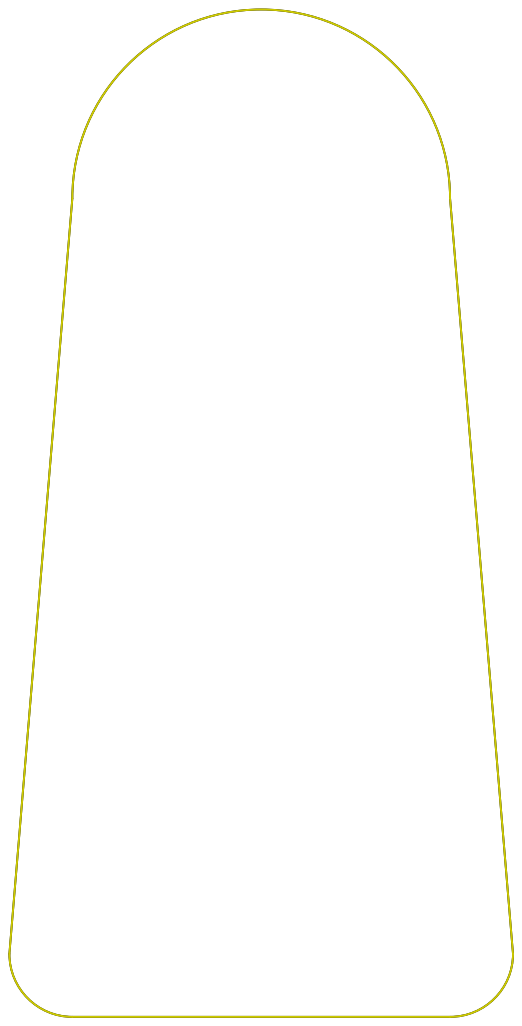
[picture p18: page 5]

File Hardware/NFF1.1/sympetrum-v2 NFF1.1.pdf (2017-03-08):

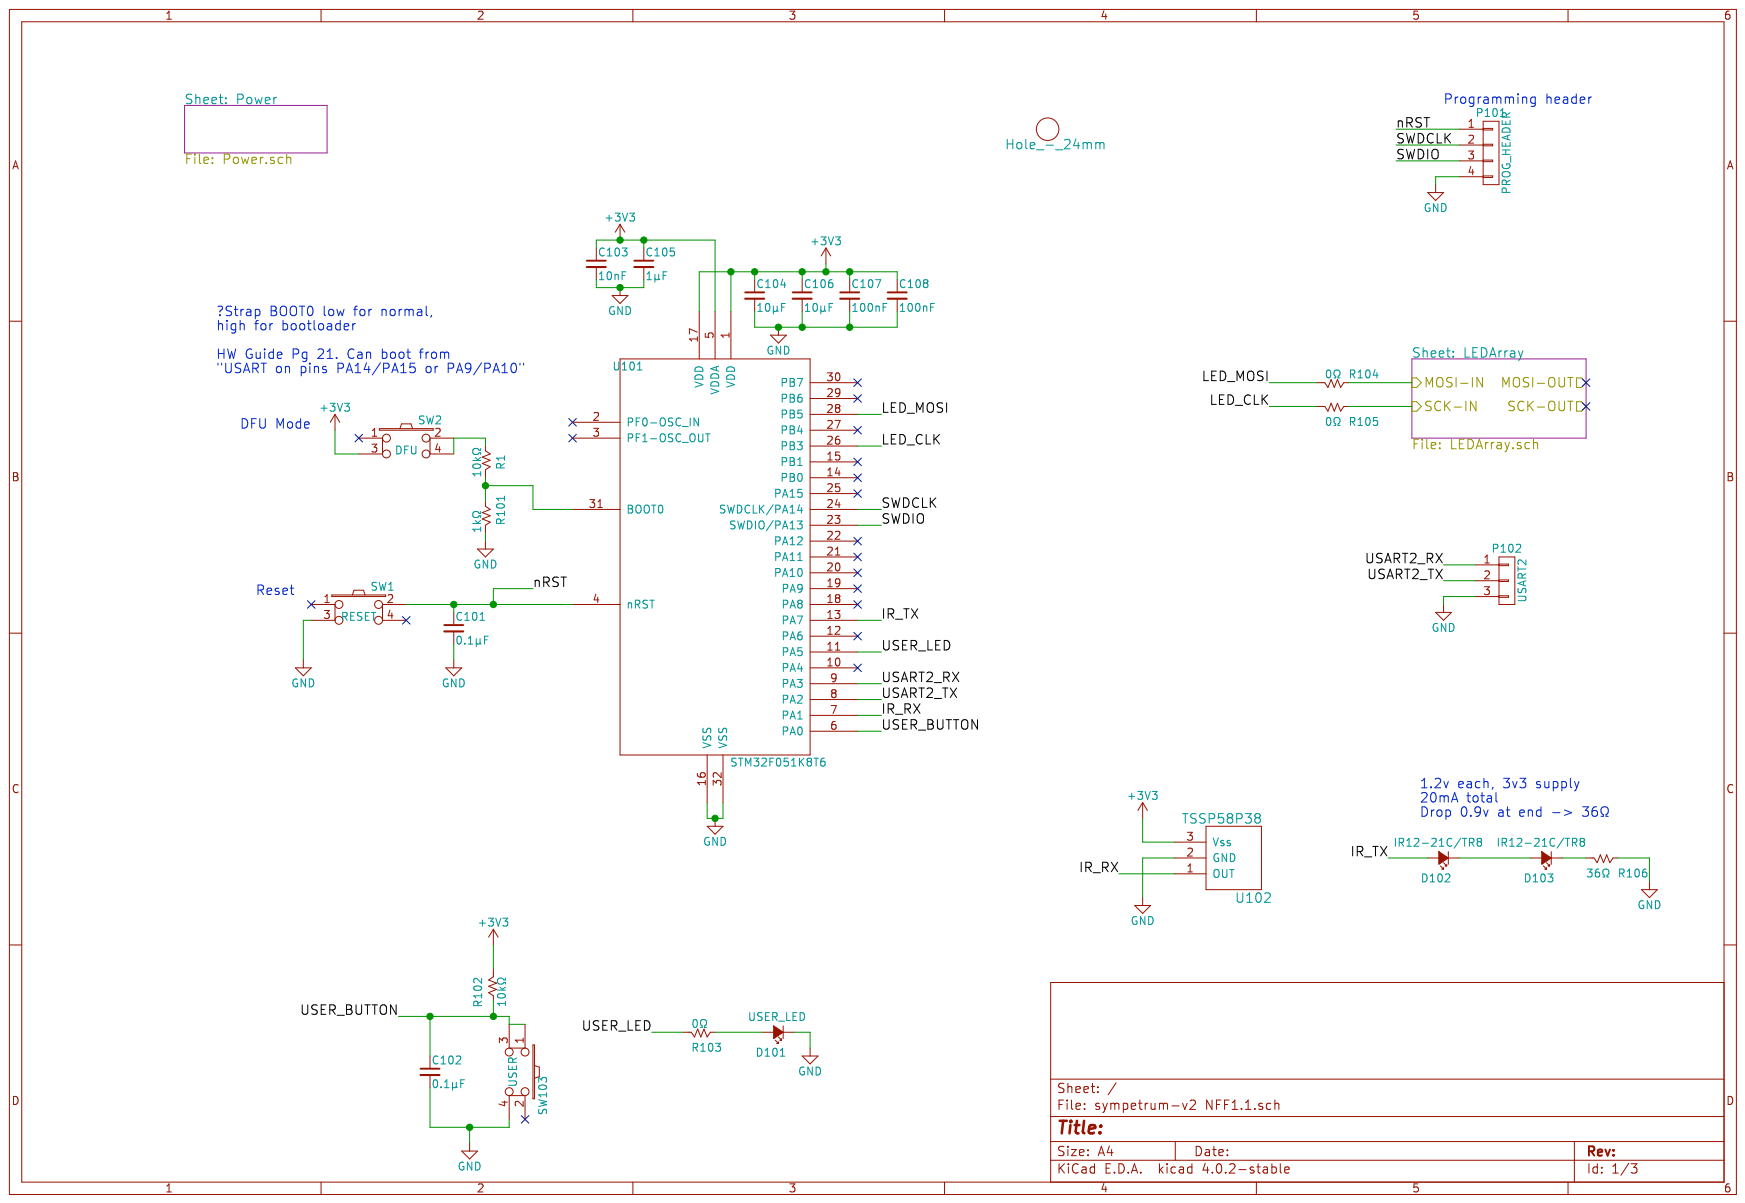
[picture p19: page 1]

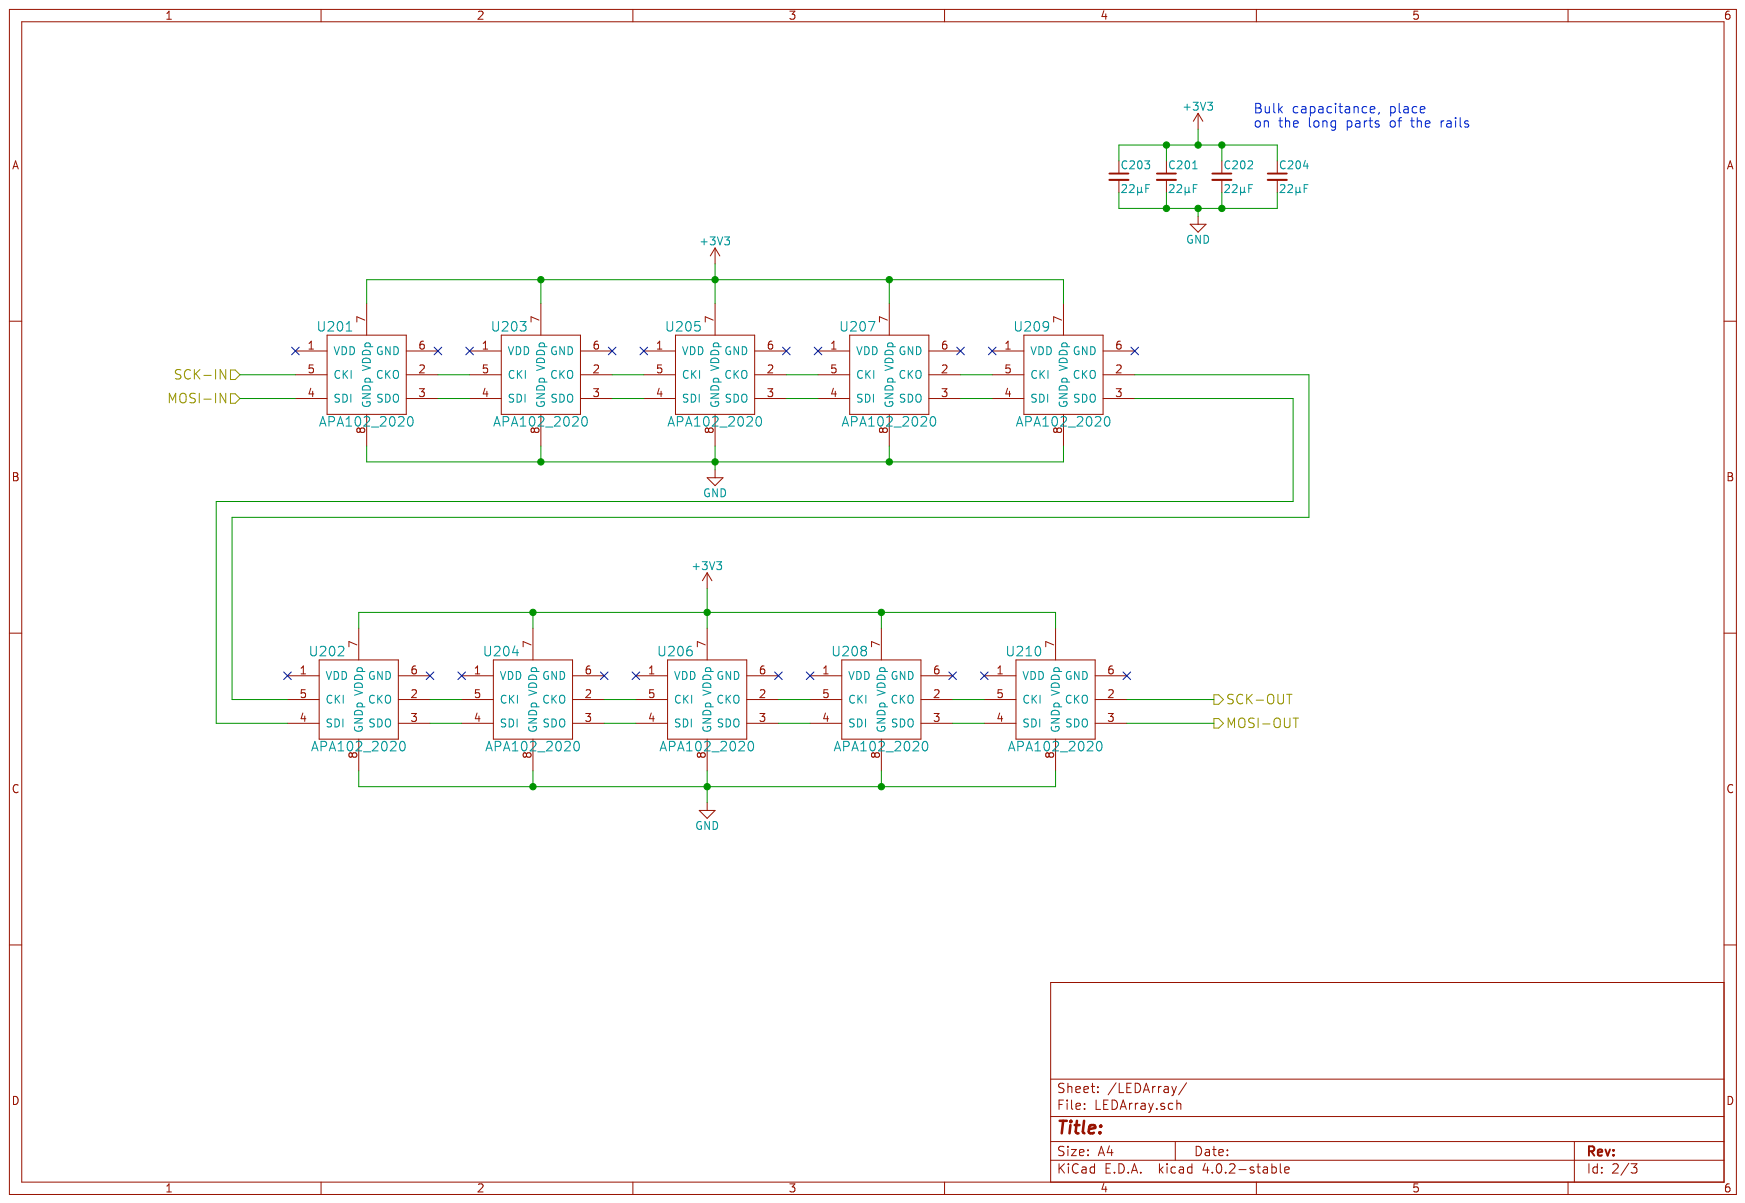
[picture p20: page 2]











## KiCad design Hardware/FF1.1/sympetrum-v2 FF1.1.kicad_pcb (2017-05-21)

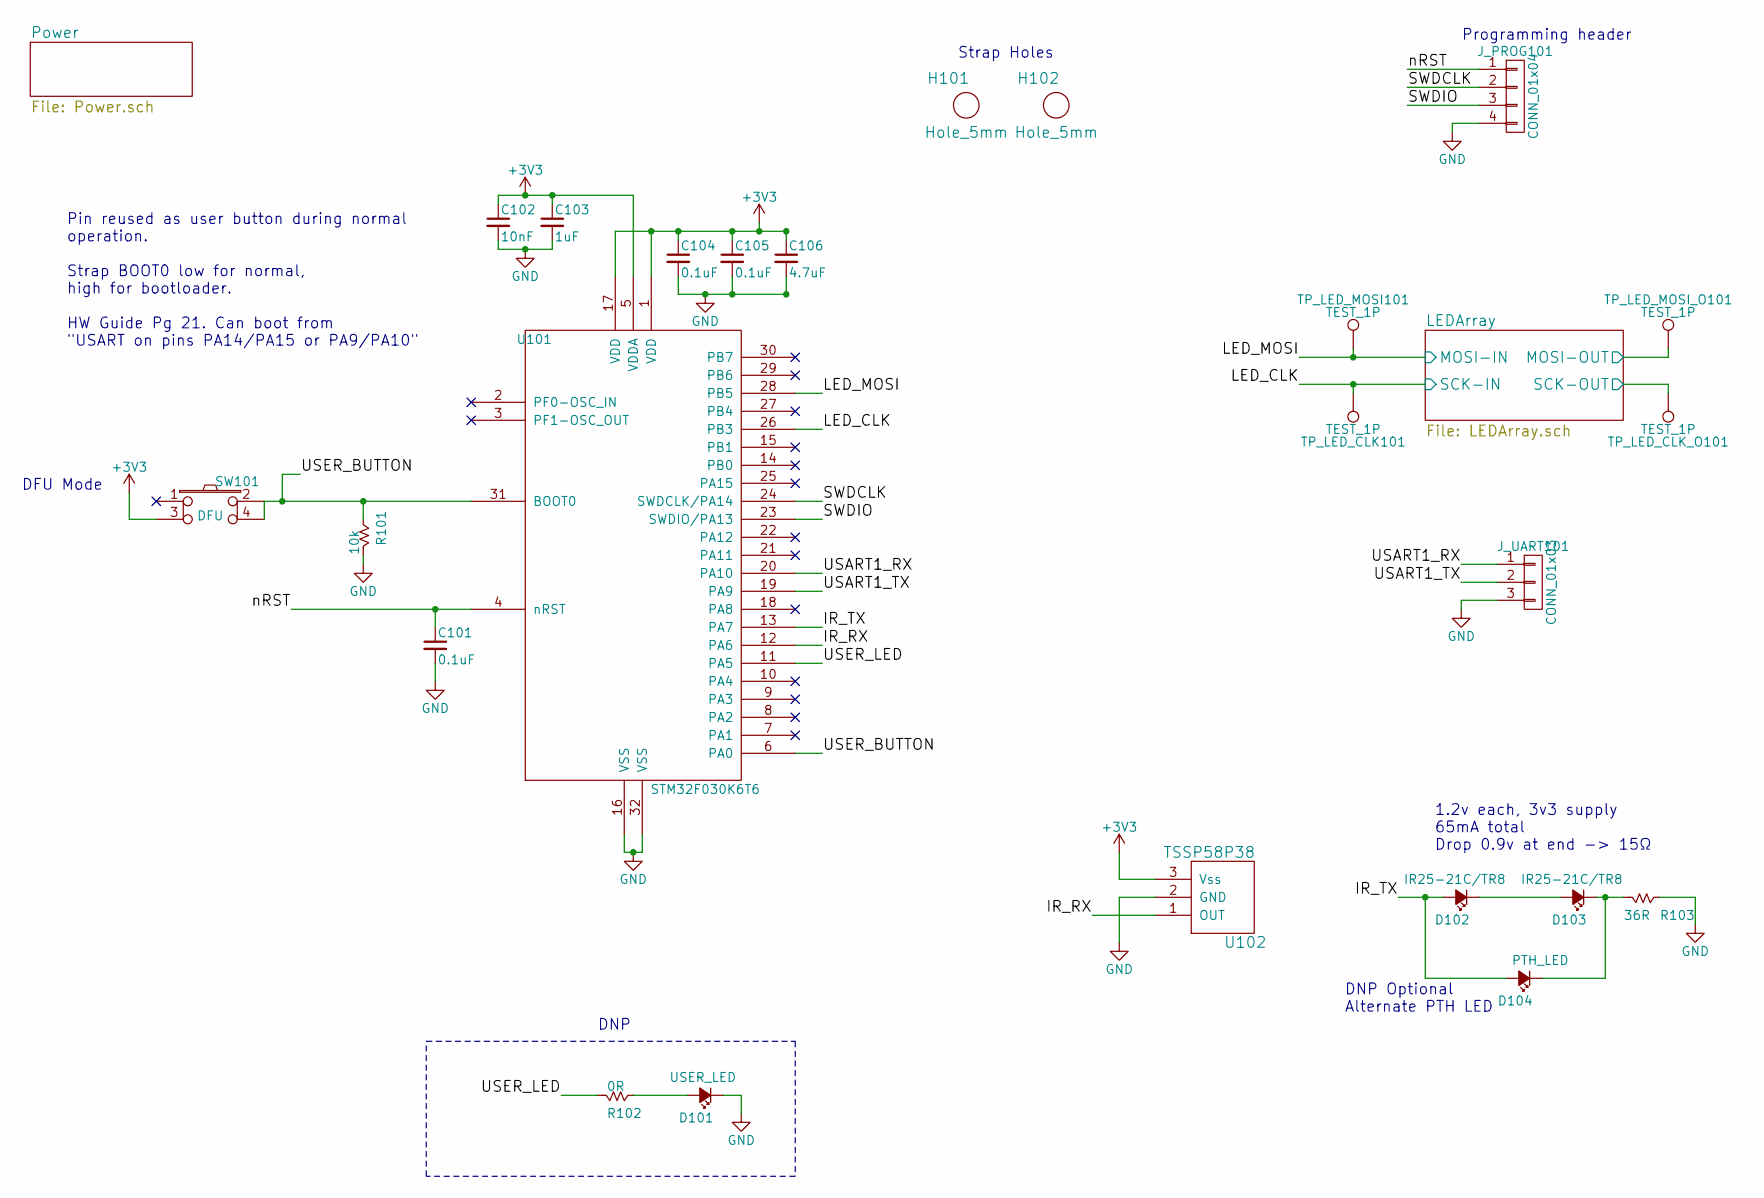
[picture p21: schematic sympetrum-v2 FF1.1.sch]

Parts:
C101, C104, C105: 0.1uF; C_0805; MPN 08055C104KAT2A
C102: 10nF; C_0805; MPN CC0805KRX7R9BB103
C103: 1uF; C_0805; MPN CC0805KKX7R7BB105
C106: 4.7uF; C_0805; MPN CL21F475ZPFNNNE
D101: USER_LED; LED_0805
D102, D103: IR25-21C/TR8; LED_1206; MPN IR25-21C/TR8; DigiKey 1080-1356-1-ND
D104: PTH_LED; LED-5MM-NoSilk; DigiKey 1080-1356-1-ND
H101, H102: Hole_5mm; Home_5mm
J_PROG101: CONN_01x04; Pin_Header_Straight_1x04
J_UART101: CONN_01x03; Pin_Header_Straight_1x03
R101: 10k; R_0805; MPN RC0805FR-0710KL
R102: 0R; R_0805; MPN RC0805JR-070RL
R103: 36R; R_0805; MPN RC0805FR-0736RL
SW101: DFU; SW_SPST_EVQP0_DPLIT
TP_LED_CLK101: TEST_1P; Measurement_Point_Round-SMD-Pad_Small
TP_LED_CLK_O101: TEST_1P; Measurement_Point_Round-SMD-Pad_Small
TP_LED_MOSI101: TEST_1P; Measurement_Point_Round-SMD-Pad_Small
TP_LED_MOSI_O101: TEST_1P; Measurement_Point_Round-SMD-Pad_Small
U101: STM32F030K6T6; LQFP-32_7x7mm_Pitch0.8mm; MPN STM32F030K6T6; DigiKey 497-12892-ND
U102: TSSP58P38; TO-220_Neutral123_Vertical_LayDown-NoSilk; MPN TSSP58P38; DigiKey TSSP58P38-ND

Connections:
/IR_RX: U101.12 (PA6), U102.1 (OUT)
/IR_TX: D102.2 (A), D104.2 (A), U101.13 (PA7)
/LEDArray/MOSI-OUT: TP_LED_MOSI_O101.1; also elsewhere on the board
/LEDArray/SCK-OUT: TP_LED_CLK_O101.1; also elsewhere on the board
/LED_CLK: TP_LED_CLK101.1, U101.26 (PB3); also elsewhere on the board
/LED_MOSI: TP_LED_MOSI101.1, U101.28 (PB5); also elsewhere on the board
/SWDCLK: J_PROG101.2, U101.24 (SWDCLK/PA14)
/SWDIO: J_PROG101.3, U101.23 (SWDIO/PA13)
/USART1_RX: J_UART101.1, U101.20 (PA10)
/USART1_TX: J_UART101.2, U101.19 (PA9)
/USER_BUTTON: R101.1, SW101.2, SW101.4, U101.6 (PA0), U101.31 (BOOT0)
/USER_LED: R102.2, U101.11 (PA5)
/nRST: C101.1, J_PROG101.1, U101.4 (nRST)
GND: C101.2, C102.2, C103.2, C104.2, C105.2, C106.2, D101.1 (K), J_PROG101.4, J_UART101.3, R101.2, R103.1, U101.16 (VSS), U101.32 (VSS), U102.2 (GND); also elsewhere on the board
unnamed: D101.2 (A), R102.1
unnamed: D102.1 (K), D103.2 (A)
unnamed: D103.1 (K), D104.1 (K), R103.2

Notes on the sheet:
Pin reused as user button during normal operation. Strap BOOT0 low for normal, high for bootloader. HW Guide Pg 21. Can boot from "USART on pins PA14/PA15 or PA9/PA10"
Programming header
DFU Mode
1.2v each, 3v3 supply 65mA total Drop 0.9v at end -> 15Ω
Strap Holes
DNP
DNP Optional Alternate PTH LED

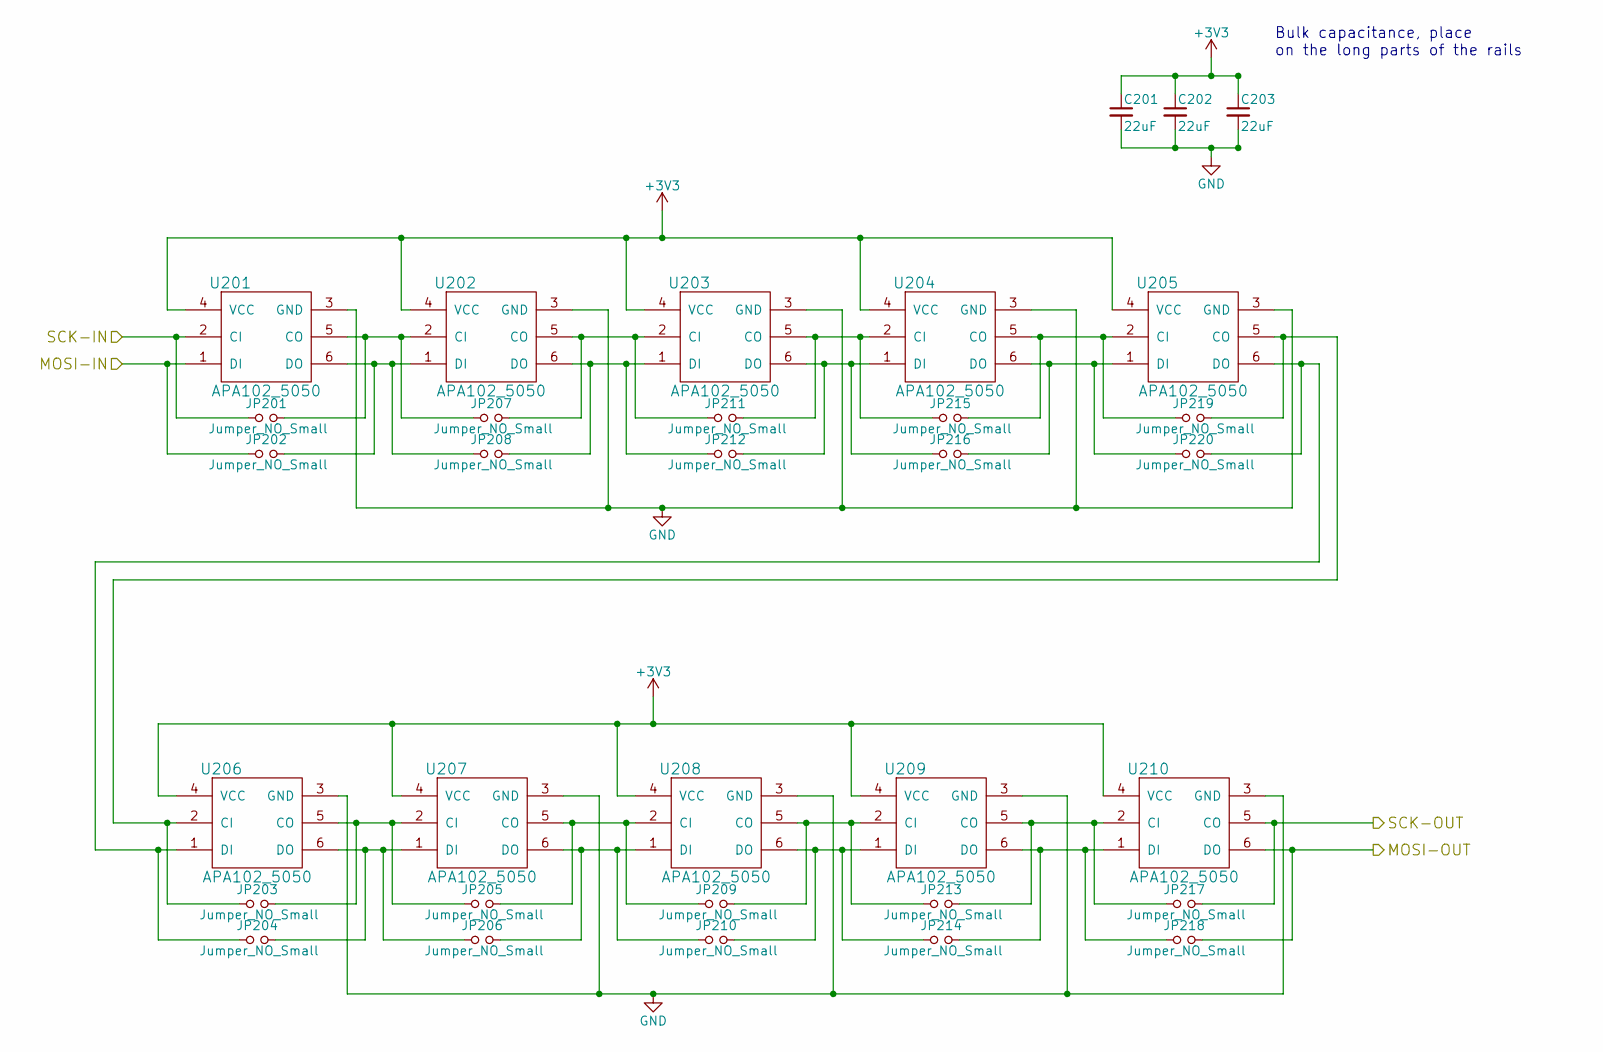
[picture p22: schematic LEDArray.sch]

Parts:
C201, C202, C203: 22uF; C_0805; MPN CL21A226KQCLRNC
JP201, JP202, JP203, JP204, JP205, JP206, JP207, JP208, JP209, JP210, JP211, JP212, JP213, JP214, JP215, JP216, JP217, JP218, JP219, JP220: Jumper_NO_Small; SOLDER-JUMPER_1-WAY
U201, U202, U203, U204, U205, U206, U207, U208, U209, U210: APA102_5050; LED-5050

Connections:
/LEDArray/MOSI-OUT: JP218.2, U210.6 (DO); also elsewhere on the board
/LEDArray/SCK-OUT: JP217.2, U210.5 (CO); also elsewhere on the board
/LED_CLK: JP201.1, U201.2 (CI); also elsewhere on the board
/LED_MOSI: JP202.1, U201.1 (DI); also elsewhere on the board
GND: C201.2, C202.2, C203.2, U201.3 (GND), U202.3 (GND), U203.3 (GND), U204.3 (GND), U205.3 (GND), U206.3 (GND), U207.3 (GND), U208.3 (GND), U209.3 (GND), U210.3 (GND); also elsewhere on the board
unnamed: JP201.2, JP207.1, U201.5 (CO), U202.2 (CI)
unnamed: JP202.2, JP208.1, U201.6 (DO), U202.1 (DI)
unnamed: JP203.1, JP219.2, U205.5 (CO), U206.2 (CI)
unnamed: JP203.2, JP205.1, U206.5 (CO), U207.2 (CI)
unnamed: JP204.1, JP220.2, U205.6 (DO), U206.1 (DI)
unnamed: JP204.2, JP206.1, U206.6 (DO), U207.1 (DI)
unnamed: JP205.2, JP209.1, U207.5 (CO), U208.2 (CI)
unnamed: JP206.2, JP210.1, U207.6 (DO), U208.1 (DI)
unnamed: JP207.2, JP211.1, U202.5 (CO), U203.2 (CI)
unnamed: JP208.2, JP212.1, U202.6 (DO), U203.1 (DI)
unnamed: JP209.2, JP213.1, U208.5 (CO), U209.2 (CI)
unnamed: JP210.2, JP214.1, U208.6 (DO), U209.1 (DI)
unnamed: JP211.2, JP215.1, U203.5 (CO), U204.2 (CI)
unnamed: JP212.2, JP216.1, U203.6 (DO), U204.1 (DI)
unnamed: JP213.2, JP217.1, U209.5 (CO), U210.2 (CI)
unnamed: JP214.2, JP218.1, U209.6 (DO), U210.1 (DI)
unnamed: JP215.2, JP219.1, U204.5 (CO), U205.2 (CI)
unnamed: JP216.2, JP220.1, U204.6 (DO), U205.1 (DI)

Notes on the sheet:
Bulk capacitance, place on the long parts of the rails

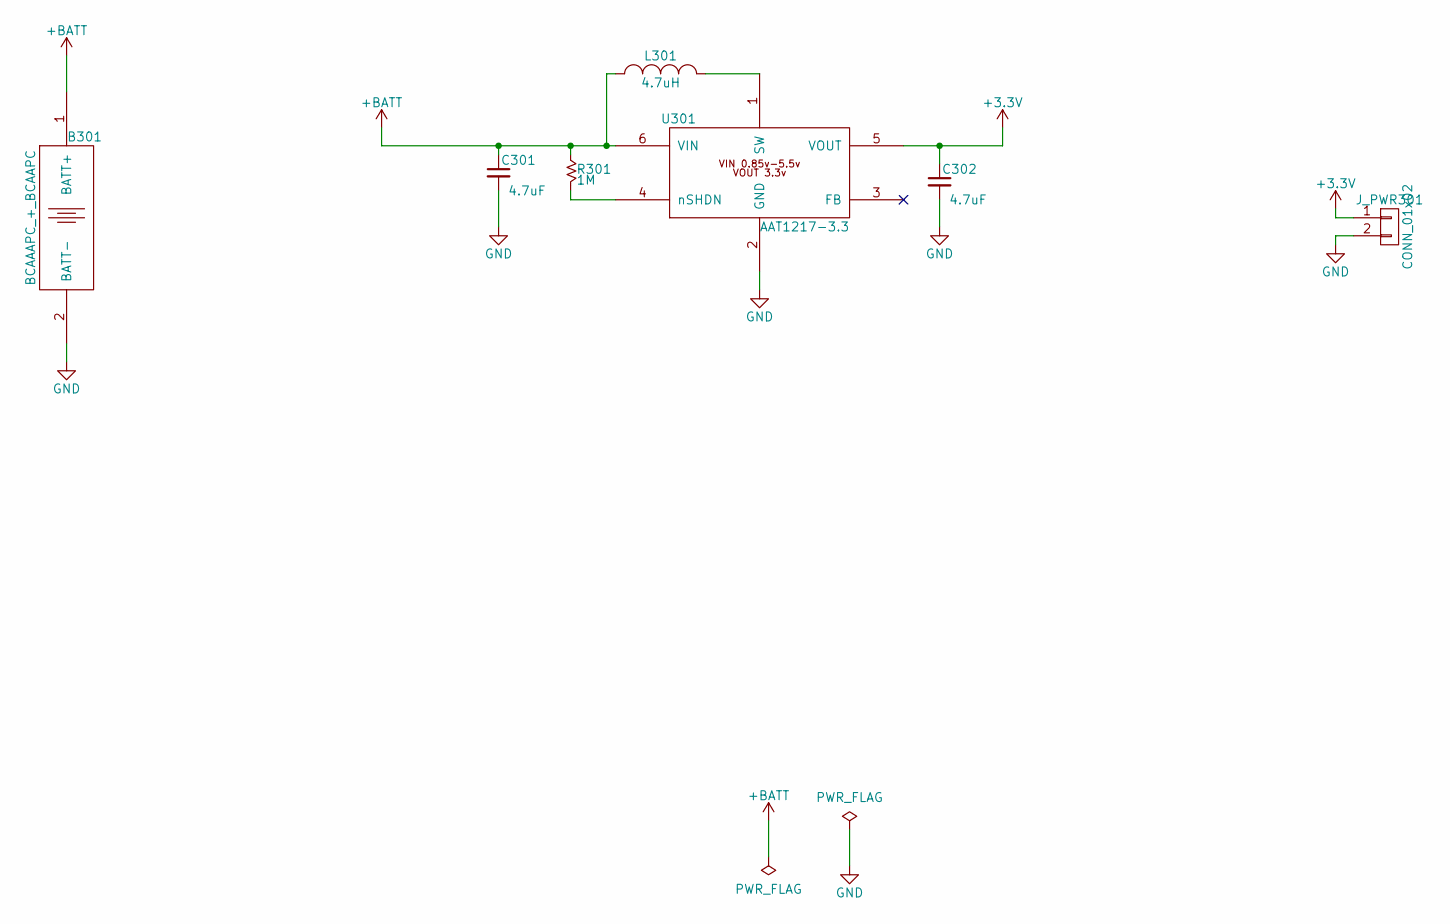
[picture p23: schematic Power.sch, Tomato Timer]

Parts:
B301: BCAAAPC_+_BCAAPC; BCAAAPC+BCAAPC-ChinaFixed; DigiKey BCAAAPC-ND
C301, C302: 4.7uF; C_0805; MPN CL21F475ZPFNNNE
J_PWR301: CONN_01x02; Pin_Header_Straight_1x02
L301: 4.7uH; Inductor_1212; MPN LQH3NPN4R7NJ0L
R301: 1M; R_0805; MPN RC0805FR-071ML
U301: AAT1217-3.3; SOT-23-6; MPN AAT1217ICA-3.3-T1; DigiKey 863-1496-1-ND

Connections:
+BATT: B301.1 (BATT+), C301.1, L301.1, R301.1, U301.6 (VIN)
GND: B301.2 (BATT-), C301.2, C302.2, J_PWR301.2, U301.2 (GND); also elsewhere on the board
unnamed: L301.2, U301.1 (SW)
unnamed: R301.2, U301.4 (nSHDN)

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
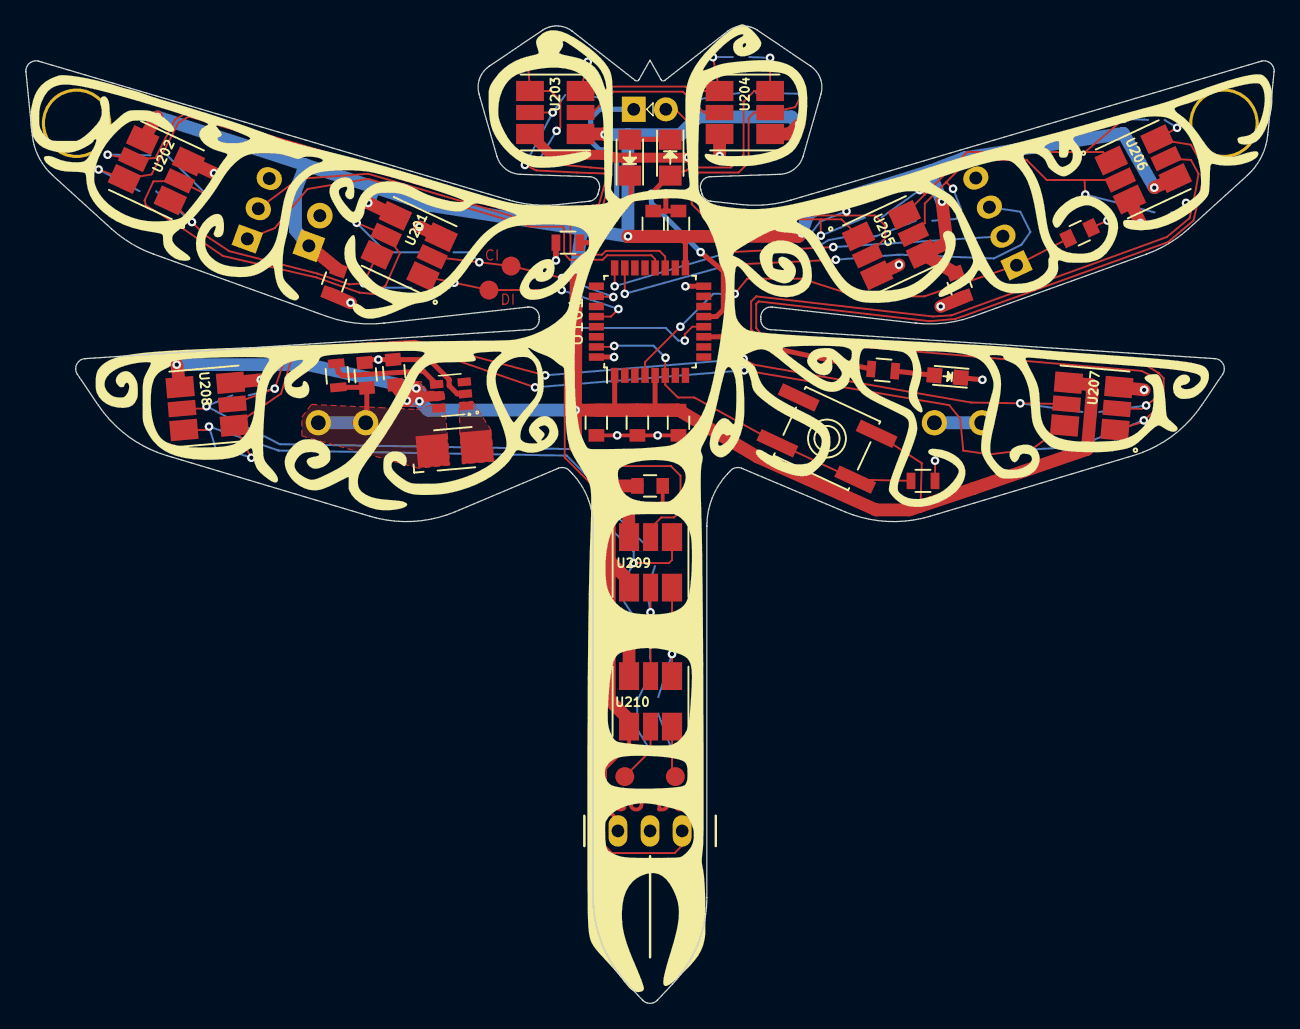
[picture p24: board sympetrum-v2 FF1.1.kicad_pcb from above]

Board: 2 copper layers, 98.8 x 77.3 mm, 64 parts (0 on the bottom side), 39 nets.

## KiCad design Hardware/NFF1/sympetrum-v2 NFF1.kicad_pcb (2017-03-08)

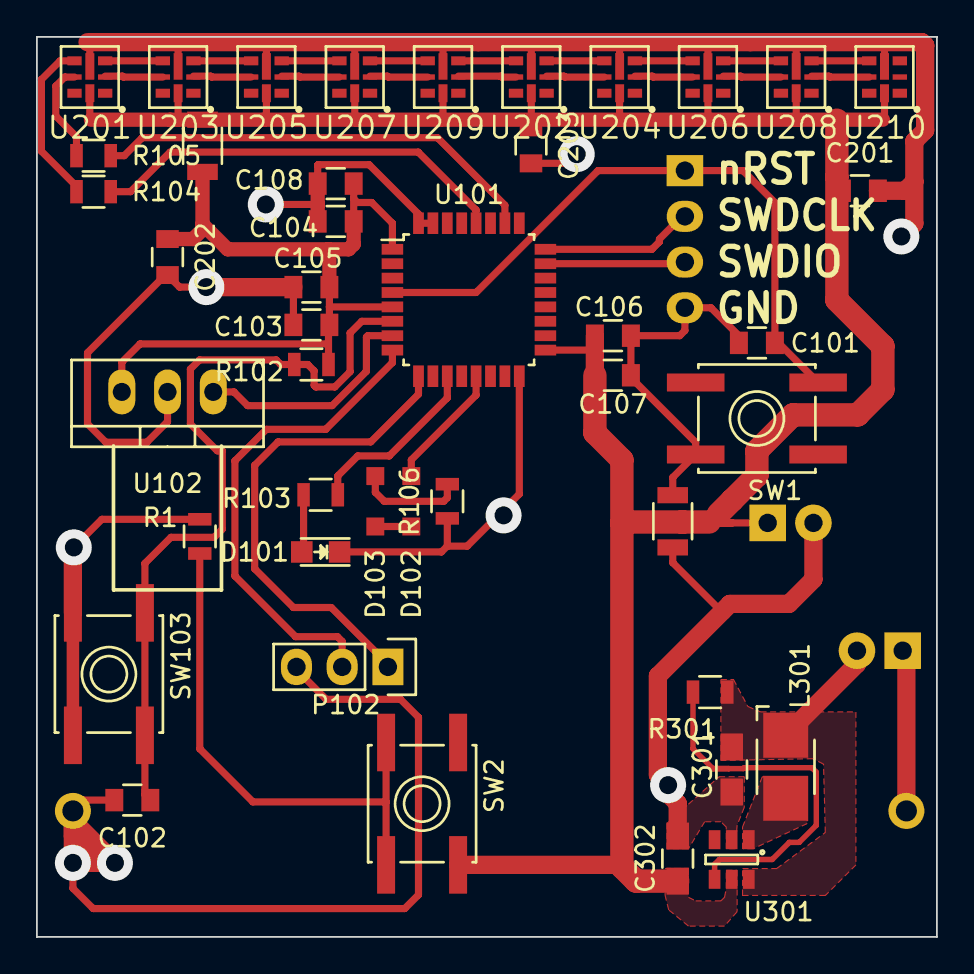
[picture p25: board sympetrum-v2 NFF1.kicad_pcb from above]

Board: 2 copper layers, 50.0 x 50.0 mm, 47 parts (0 on the bottom side), 41 nets.

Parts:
B301: BCAAAPC
C101, C102: 0.1µF; C_0805
C103: 10nF; C_0805
C104, C106: 10µF; C_0805
C105: 1µF; C_0805
C107, C108: 100nF; C_0805
C201, C202, C203: 22µF; C_0805
C301, C302: 4.7uF; C_0805_HandSoldering
D101: USER_LED; LED_0805
D102, D103: IR12-21C/TR8; Everlight-IR12-21C-TR8
JP301: JP_POWER; Socket_Strip_Straight_1x02
L301: 4.7uH; Inductor_1212
P101: PROG_HEADER; Pin_Header_Straight_1x04
P102: USART2; Pin_Header_Straight_1x03
P301: DBG_PWR; Pin_Header_Straight_1x02
R1, R102: 10kΩ; R_0805
R103, R104, R105: 0Ω; R_0805
R106: 36Ω; R_0805
R301: 1MΩ; R_0805
REFa**: R_1206
REFt**: R_1206
SW1: RESET; SW_SPST_EVQP0_DPLIT
SW2: DFU; SW_SPST_EVQP0_DPLIT
SW103: USER; SW_SPST_EVQP0_DPLIT
U101: STM32F051K8T6; LQFP-32_7x7mm_Pitch0.8mm
U102: TSSP58P38; TO-220_Neutral123_Vertical_LayDown
U201, U202, U203, U204, U205, U206, U207, U208, U209, U210: APA102_2020; APA102_2020_LED_Complex_Split
U301: AAT1217-3.3; SOT-23-6

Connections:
+3V3: C103.1, C104.1, C105.1, C106.1, C107.1, C108.1, C201.1, C202.1, C203.1, C302.1, P301.1, R102.2, REFt**.1, REFt**.2, SW2.3, U101.1, U101.5, U101.17, U102.3, U201.7, U202.7, U203.7, U204.7, U205.7, U206.7, U207.7, U208.7, U209.7, U210.7, U301.5
+BATT: B301.1, JP301.1
/IR_RX: U101.7, U102.1
/IR_TX: D102.2, U101.13
/LEDArray/MOSI-IN: R104.1, U201.4
/LEDArray/SCK-IN: R105.1, U201.5
/LED_CLK: R105.2, U101.26
/LED_MOSI: R104.2, U101.28
/Power/VIN: C301.1, JP301.2, L301.1, R301.1, U301.6
/SWDCLK: P101.2, U101.24
/SWDIO: P101.3, U101.23
/USART2_RX: P102.1, U101.9
/USART2_TX: P102.2, U101.8
/USER_BUTTON: C102.1, R102.1, SW103.1, SW103.3, U101.6
/USER_LED: R103.2, U101.11
/nRST: C101.1, P101.1, SW1.2, U101.4
GND: B301.2, C101.2, C102.2, C103.2, C104.2, C105.2, C106.2, C107.2, C108.2, C201.2, C202.2, C203.2, C301.2, C302.2, D101.1, P101.4, P102.3, P301.2, R1.2, R106.1, REFa**.1, SW1.3, SW103.2, SW103.4, U101.16, U101.31, U101.32, U102.2, U201.8, U202.8, U203.8, U204.8, U205.8, U206.8, U207.8, U208.8, U209.8, U210.8, U301.2
unnamed: D101.2, R103.1
unnamed: D102.1, D103.2
unnamed: D103.1, R106.2
unnamed: L301.2, U301.1
unnamed: R1.1, SW2.2, SW2.4
unnamed: R301.2, U301.4
unnamed: U201.2, U203.5
unnamed: U201.3, U203.4
unnamed: U202.2, U204.5
unnamed: U202.3, U204.4
unnamed: U202.4, U209.3
unnamed: U202.5, U209.2
unnamed: U203.2, U205.5
unnamed: U203.3, U205.4
unnamed: U204.2, U206.5
unnamed: U204.3, U206.4
unnamed: U205.2, U207.5
unnamed: U205.3, U207.4
unnamed: U206.2, U208.5
unnamed: U206.3, U208.4
unnamed: U207.2, U209.5
unnamed: U207.3, U209.4
unnamed: U208.2, U210.5
unnamed: U208.3, U210.4

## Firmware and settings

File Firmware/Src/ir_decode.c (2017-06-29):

/**
  TODO update this block
 */

#include "ir_decode.h"
#include "iprintf.h"

#include "stm32f0xx_hal.h"
#include "stm32f0xx_hal_tim.h"

#include <stdint.h>
#include <stdbool.h>


#define RC5_1T_TIME                          0x00
#define RC5_2T_TIME                          0x01
#define RC5_WRONG_TIME                       0xFF
#define RC5_TIME_OUT_US                      3600
#define RC5_T_US                             900     /*!< Half bit period */
#define RC5_T_TOLERANCE_US                   270    /*!< Tolerance time */
#define RC5_NUMBER_OF_VALID_PULSE_LENGTH     2
//13 bits to allow 1 to be lost to syncing
#define RC5_PACKET_BIT_COUNT                 13      /*!< Total bits */

/* Packet struct for reception*/
#define RC5_PACKET_STATUS_EMPTY              false 

#define TIM_PRESCALER                        47                       /* !< TIM prescaler */

typedef struct
{
   __IO uint16_t data;     /*!< RC5 data */
   __IO bool     status;   /*!< RC5 status */
   __IO uint8_t  lastBit;  /*!< RC5 last bit */
   __IO uint8_t  bitCount; /*!< RC5 bit count */
} tRC5_packet;

enum RC5_lastBitType
{
   RC5_ZER,
   RC5_ONE,
   RC5_NAN,
   RC5_INV
};
typedef enum RC5_lastBitType tRC5_lastBitType;

/* Logic table for rising edge: every line has values corresponding to previous bit.
   In columns are actual bit values for given bit time. */
const tRC5_lastBitType RC5_logicTableRisingEdge[2][2] =
{
   {RC5_ZER ,RC5_INV}, /* lastbit = ZERO */
   {RC5_NAN ,RC5_ZER}, /* lastbit = ONE  */
};

/* Logic table for falling edge: every line has values corresponding to previous bit. 
   In columns are actual bit values for given bit time. */
const tRC5_lastBitType RC5_logicTableFallingEdge[2][2] =
{
   {RC5_NAN ,RC5_ONE},  /* lastbit = ZERO */
   {RC5_ONE ,RC5_INV},  /* lastbit = ONE  */
};

//FIXME encapsulate this
//not static so IT can see it
TIM_HandleTypeDef htim3;

__IO bool RC5FrameReceived = false; /*!< RC5 Frame state */ 
__IO tRC5_packet   RC5TmpPacket;          /*!< First empty packet */

/* RC5  bits time definitions */
static uint16_t  RC5MinT = 0;
static uint16_t  RC5MaxT = 0;
static uint16_t  RC5Min2T = 0;
static uint16_t  RC5Max2T = 0;
static uint32_t TIMCLKValueKHz = 0; /*!< Timer clock */
static uint16_t RC5TimeOut = 0;
RC5_Frame_TypeDef RC5_FRAME;

static uint8_t RC5_GetPulseLength (uint16_t pulseLength);
static void RC5_modifyLastBit(tRC5_lastBitType bit);
static void RC5_WriteBit(uint8_t bitVal);
static uint32_t TIM_GetCounterCLKValue(void);

/**
 * @brief  Initialize the RC5 decoder module ( Time range)
 * @param  None
 * @retval None
 */
void ir_InitDecode(void)
{ 
   TIM_ClockConfigTypeDef sClockSourceConfig;
   TIM_SlaveConfigTypeDef sSlaveConfig;
   TIM_MasterConfigTypeDef sMasterConfig;
   TIM_IC_InitTypeDef sConfigIC;

   //calculate timeouts
   TIMCLKValueKHz = TIM_GetCounterCLKValue()/1000;
   RC5TimeOut = TIMCLKValueKHz * (RC5_TIME_OUT_US / 1000);
   iprintf("Value KHz = %d\r\n", TIMCLKValueKHz);
   iprintf("RC5 timeout = %d\r\n", RC5TimeOut);

   htim3.Instance = TIM3;
   htim3.Init.Prescaler = 47;
   htim3.Init.CounterMode = TIM_COUNTERMODE_UP;
   htim3.Init.Period = RC5TimeOut;
   htim3.Init.ClockDivision = TIM_CLOCKDIVISION_DIV1;
   htim3.Init.AutoReloadPreload = TIM_AUTORELOAD_PRELOAD_ENABLE;
   if (HAL_TIM_Base_Init(&htim3) != HAL_OK)
   {
      iprintf("ERROR\r\n");
   }

   sClockSourceConfig.ClockSource = TIM_CLOCKSOURCE_INTERNAL;
   if (HAL_TIM_ConfigClockSource(&htim3, &sClockSourceConfig) != HAL_OK)
   {
      iprintf("ERROR\r\n");
   }

   if (HAL_TIM_IC_Init(&htim3) != HAL_OK)
   {
      iprintf("ERROR\r\n");
   }

   sSlaveConfig.SlaveMode = TIM_SLAVEMODE_RESET;
   sSlaveConfig.InputTrigger = TIM_TS_TI1FP1;
   sSlaveConfig.TriggerPolarity = TIM_INPUTCHANNELPOLARITY_BOTHEDGE;
   sSlaveConfig.TriggerFilter = 0;
   if (HAL_TIM_SlaveConfigSynchronization(&htim3, &sSlaveConfig) != HAL_OK)
   {
      iprintf("ERROR\r\n");
   }

   sMasterConfig.MasterOutputTrigger = TIM_TRGO_RESET;
   sMasterConfig.MasterSlaveMode = TIM_MASTERSLAVEMODE_ENABLE;
   if (HAL_TIMEx_MasterConfigSynchronization(&htim3, &sMasterConfig) != HAL_OK)
   {
      iprintf("ERROR\r\n");
   }

   sConfigIC.ICPolarity = TIM_INPUTCHANNELPOLARITY_BOTHEDGE;
   sConfigIC.ICSelection = TIM_ICSELECTION_DIRECTTI;
   sConfigIC.ICPrescaler = TIM_ICPSC_DIV1;
   sConfigIC.ICFilter = 0;
   if (HAL_TIM_IC_ConfigChannel(&htim3, &sConfigIC, TIM_CHANNEL_1) != HAL_OK)
   {
      iprintf("ERROR\r\n");
   }

   /* Enable TIM Update Event Interrupt Request */
   __HAL_TIM_CLEAR_FLAG(&htim3, TIM_FLAG_UPDATE);
   __HAL_TIM_ENABLE_IT(&htim3, TIM_FLAG_UPDATE);

   /* Bit time range */
   RC5MinT = (RC5_T_US - RC5_T_TOLERANCE_US) * TIMCLKValueKHz / 1000;
   RC5MaxT = (RC5_T_US + RC5_T_TOLERANCE_US) * TIMCLKValueKHz / 1000;
   RC5Min2T = (2 * RC5_T_US - RC5_T_TOLERANCE_US) * TIMCLKValueKHz / 1000;
   RC5Max2T = (2 * RC5_T_US + RC5_T_TOLERANCE_US) * TIMCLKValueKHz / 1000;

   iprintf("MinT = %d, MaxT = %d\r\n", RC5MinT, RC5MaxT);
   iprintf("Min2T = %d, Max2T = %d\r\n", RC5Min2T, RC5Max2T);

   /* Default state */
   ir_ResetPacket();

   HAL_TIM_IC_Start_IT(&htim3, TIM_CHANNEL_1);
}

/**
 * Temporarily disable the RX pipeline (for when we are transmitting).
 */
void ir_DecodeDisable(void) {
   HAL_TIM_IC_Stop_IT(&htim3, TIM_CHANNEL_1);
   ir_ResetPacket();
}

void ir_DecodeEnable(void) {
   ir_ResetPacket();
   __HAL_TIM_CLEAR_IT(&htim3, TIM_FLAG_UPDATE);
   __HAL_TIM_CLEAR_FLAG(&htim3, TIM_FLAG_UPDATE);
   HAL_TIM_IC_Start_IT(&htim3, TIM_CHANNEL_1);
}
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

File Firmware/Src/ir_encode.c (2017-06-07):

/*
 */
#include "ir_encode.h"
#include "platform_hw.h"
#include "iprintf.h"

#include "stm32f0xx.h"
#include "stm32f0xx_it.h"
#include "stm32f0xx_hal.h"
#include "stm32f0xx_hal_tim.h"

#include <stdint.h>

#define  RC5HIGHSTATE     ((uint8_t )0x02)   /* RC5 high level definition*/
#define  RC5LOWSTATE      ((uint8_t )0x01)   /* RC5 low level definition*/

static uint8_t RC5_RealFrameLength = 14;
static uint8_t RC5_GlobalFrameLength = 64;
static uint16_t RC5_FrameBinaryFormat = 0;
static uint32_t RC5_FrameManchestarFormat = 0;
static uint8_t Send_Operation_Ready = 0;
__IO bool Send_Operation_Completed = true;
static uint8_t BitsSent_Counter = 0;

//FIXME encapsulate this
//not static so IT can see it
TIM_HandleTypeDef htim16;
static TIM_HandleTypeDef htim17;

static uint16_t RC5_BinFrameGeneration(uint8_t RC5_Address, uint8_t RC5_Instruction, RC5_Ctrl_TypeDef RC5_Ctrl);
static uint32_t RC5_ManchesterConvert(uint16_t RC5_BinaryFrameFormat);
static void TIM17_Init(void);
static void TIM16_Init(void);

void ir_InitEncode(void)
{
   TIM17_Init();
   TIM16_Init();
}

/**
 * @brief  Generate and Send the RC5 frame.
 * @param  RC5_Address: the RC5 Device destination 
 * @param  RC5_Instruction: the RC5 command instruction 
 * @param  RC5_Ctrl: the RC5 Control bit.
 * @retval None
 */
void ir_SendRC5(uint8_t RC5_Address, uint8_t RC5_Instruction, RC5_Ctrl_TypeDef RC5_Ctrl)
{
   ir_SendRaw(RC5_BinFrameGeneration(RC5_Address, RC5_Instruction, RC5_Ctrl));
}

/**
 * Send an unstructured 14 bit messags.
 */
void ir_SendRaw(uint16_t message)
{
   HAL_StatusTypeDef res;
   uint16_t frameBinaryFormat = 0;

   // make sure there is a start bit set
   frameBinaryFormat = message | (1 << (RC5_RealFrameLength - 1));

   /* Generate a Manchester format of the Frame */
   RC5_FrameManchestarFormat = RC5_ManchesterConvert(frameBinaryFormat);

   /* Set the Send operation Ready flag to indicate that the frame is ready to be sent */
   Send_Operation_Ready = 1;

   //start the bit clock. Each edge it will send data on its own
   res = HAL_TIM_Base_Start_IT(&htim16);
   if(res != HAL_OK) {
      iprintf("Failed to start TIM16 CH1 to send\r\n");
   }
}

/**
 * @brief  Send by hardware Manchester Format RC5 Frame.
 * @param  RC5_BinaryFrameFormat: the RC5 frame in binary format.
 * @retval Noe
 */
void ir_SignalGenerate(void)
{
   uint8_t bit_msg = 0;

   if((Send_Operation_Ready == 1) && (BitsSent_Counter <= (RC5_GlobalFrameLength * 2)))
   {
      Send_Operation_Completed = false;
      bit_msg = (uint8_t)((RC5_FrameManchestarFormat >> BitsSent_Counter)& 1);

      if (bit_msg== 1)
      {
         //enable the data out clock
         HAL_TIM_PWM_Start(&htim17, TIM_CHANNEL_1);

         /*
         //FIXME rm, play out a GPIO for testing
         if(GPIO_PIN_RESET == HAL_GPIO_ReadPin(LD3_GPIO_Port, LD3_Pin)) {
         HAL_GPIO_WritePin(LD3_GPIO_Port, LD3_Pin, GPIO_PIN_SET);
         }
          */
         /*
         if(GPIO_PIN_SET == HAL_GPIO_ReadPin(LD3_GPIO_Port, LD3_Pin)) {
            HAL_GPIO_WritePin(LD3_GPIO_Port, LD3_Pin, GPIO_PIN_RESET);
         }
         */
      }
      else
      {
         //FIXME rm, play out a GPIO for testing
         HAL_TIM_PWM_Stop(&htim17, TIM_CHANNEL_1);

         /*
         //FIXME rm
         if(GPIO_PIN_SET == HAL_GPIO_ReadPin(LD3_GPIO_Port, LD3_Pin)) {
         HAL_GPIO_WritePin(LD3_GPIO_Port, LD3_Pin, GPIO_PIN_RESET);
         }
          */
         /*
         if(GPIO_PIN_RESET == HAL_GPIO_ReadPin(LD3_GPIO_Port, LD3_Pin)) {
            HAL_GPIO_WritePin(LD3_GPIO_Port, LD3_Pin, GPIO_PIN_SET);
         }
         */
      }
      BitsSent_Counter++;

      //restart timer to count to next bit edge
      HAL_TIM_Base_Start_IT(&htim16);
   }
   else
   {
      Send_Operation_Completed = true;

      HAL_StatusTypeDef res;

      res = HAL_TIM_Base_Stop_IT(&htim16);
      if(res != HAL_OK) {
         iprintf("Failed to stop TIM16 after sending message\r\n");
      }

      //force TIM17's output low so it never accidentally idles high after sending
      HAL_GPIO_WritePin(GPIOA, GPIO_PIN_7, GPIO_PIN_RESET);

      Send_Operation_Ready = 0;
      BitsSent_Counter = 0;
   }
}
/**
 * @brief  Generate the binary format of the RC5 frame.
 * @param  RC5_Address: Select the device adress.
 * @param  RC5_Instruction: Select the device instruction.
 * @param  RC5_Ctrl: Select the device control bit status.
 * @retval Binary format of the RC5 Frame.
 */
static uint16_t RC5_BinFrameGeneration(uint8_t RC5_Address, uint8_t RC5_Instruction, RC5_Ctrl_TypeDef RC5_Ctrl)
{
   uint16_t star1 = 0x2000;
   uint16_t star2 = 0x1000;
   uint16_t addr = 0;

   //don't wipe out globals before they're sent!
   while(Send_Operation_Completed == false) {}

   /* Check if Instruction is 128-bit length */
   if(RC5_Instruction >= 64)
   {
      /* Reset field bit: command is 7-bit length */
      star2 = 0;
      /* Keep the lowest 6 bits of the command */
      RC5_Instruction &= 0x003F;
   }
   else /* Instruction is 64-bit length */
   {
      /* Set field bit: command is 6-bit length */
      star2 = 0x1000;
   }

   Send_Operation_Ready = 0;
   RC5_FrameManchestarFormat = 0;
   RC5_FrameBinaryFormat=0;
   addr = ((uint16_t)(RC5_Address))<<6;
   RC5_FrameBinaryFormat =  (star1)|(star2)|(RC5_Ctrl)|(addr)|(RC5_Instruction);
   return (RC5_FrameBinaryFormat);
}

/**
 * @brief  Convert the RC5 frame from binary to Manchester Format.
 * @param  RC5_BinaryFrameFormat : the RC5 frame in binary format.
 * @retval The RC5 frame in Manchester format.
 */
static uint32_t RC5_ManchesterConvert(uint16_t RC5_BinaryFrameFormat)
{
   uint8_t i=0;
   uint16_t Mask = 1;
   uint16_t bit_format = 0;
   uint32_t ConvertedMsg =0;

   for (i=0; i < RC5_RealFrameLength; i++)
   {
      bit_format =((((uint16_t)(RC5_BinaryFrameFormat))>>i)& Mask)<<i;
      ConvertedMsg = ConvertedMsg << 2;

      if(bit_format != 0 ) /* Manchester 1 -|_  */
      {
         ConvertedMsg |= RC5HIGHSTATE;
      }
      else /* Manchester 0 _|-  */
      {
         ConvertedMsg |= RC5LOWSTATE;
      }
   }
   return (ConvertedMsg);
}

bool ir_IsSending(void) {
   return (Send_Operation_Completed == false);
}
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

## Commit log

2017-01-26 Add sample project with working Makefile
    * Generated by CubeMX for a disco board
    * Makefile manually generated
    * Includes STM32Cube(1.7?) for STM32F0
2017-01-26 Pull in STM32Cube and CMSIS
    I think this is Cube 1.7?
2017-01-27 Fix Makefile to pull in startup asm
    Tested to work on a real board now!
2017-01-27 Pull in basic printf
2017-02-01 APA102 LEDs work!
2017-02-02 Add unmodified RC5 encoder/decoder
    From en.stsw-stm32153.zip, described by AN4099.
2017-02-02 Final small LED testing tweaks
2017-02-12 Pull in and slightly strip IR sample interrupt handlers
2017-02-14 SQME new Cube 1, still broken
    Runs and prints similar garbage
2017-02-15 SQME still broken. Toggling GPIO on edges detected
    [rc5_encode.c]
2017-02-15 Fix sourcefiles with improper modes
    [iprintf.c, rc5_encode.c]
2017-02-22 Force all LEDs on (or try to anyway)
2017-02-23 Starting to test user button
2017-02-23 Add EE sources for first Non Form Factor board
    Mostly brought up and tested. Runs Disco-Test code.
    [LEDArray.sch, Power.sch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]
2017-03-08 More inconclusive experiments in the user button
2017-03-08 Add NFF1.1 HW
    Coming to DirtyPCBs soon.
    [LEDArray.sch, Power.sch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]
2017-03-08 Add NFF1.1 Schematic/Layout PDFs
2017-03-10 Add rudimentary Board ID
2017-03-20 Switch from USART2 to USART1
2017-03-20 Add CMSIS support for stm32f030x6 series parts
2017-03-20 Add most basic LED control infrastructure
2017-03-25 Update LEDs to 0 them after init
2017-03-26 Remove cruft, add LEDs for debug
2017-03-26 Properly retarget TIM3 CH1
    Previously was sampling incorrect pin, wrong channel, and
    misconfigured slave settings.
2017-03-26 Get button to work at all (polled)
2017-03-26 Add support for user button interrupts
2017-05-01 Trigger button interrupt on rising edge
    Now that we are pulled down.
2017-05-01 Move UART1 to alt fxns on PA9/PA10
2017-05-09 Switch to wafer X/Y for board ID
2017-05-10 Add a function to display FW version on the device LEDs
2017-05-10 Remove deprecated DISCO board support and HW define header
2017-05-10 Pull SPI init into LED driver and modularize it
2017-05-16 Add an RC5 isSending API and clean up the Encoder
2017-05-21 Add FF1.1 Sources
    [LEDArray.sch, Outline-Rounded-Fusion.dxf, Outline-Rounded-Libre-R12-v1 (Smaller).dxf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]
2017-05-22 Preliminary integration of BAF and YABI. Flash too small!
    [led.c, platform_hw.c, platform_hw.h]
2017-05-24 Add an LED time sharing function
2017-05-24 Refactor BAF into LED and LED HW control into platform_hw
2017-05-24 SQME starting to work! Still problems
    [led.c]
2017-05-29 Make LED register header const
2017-05-29 Fix broken switch in yabi channel CB
    [led.c]
2017-06-07 Add makefile target to print object sizes
2017-06-07 Fix inverter FW version LEDs
2017-06-07 Add param to get raw IR frame
2017-06-07 Fix inverted error logic in LED SPI init
    [led.c]
2017-06-09 Pack color structs and fix broken LED register header
    [platform_hw.c, platform_hw.h]
2017-06-09 SQME crappy LED test code
2017-06-09 More properly pump LEDs in main loop
2017-06-14 Fix incorrect LED header bit order
    [platform_hw.h]
2017-06-14 Re-enable version LEDs at boot
2017-06-14 Use MS systick as LED timebase
2017-06-21 Remove printing from the interpolator
2017-06-21 Add basic beacon send/receive framework around IR
2017-06-21 Add a 'clock divider' to the LED update interval
2017-06-27 First pass crappy pattern
    Also move some LED control into pattern.
2017-06-28 Fixup code to disable RX while beacon transmitting
    [ir_decode.c]
2017-06-28 Add functions in LED to expose animation parameters
2017-06-30 Reduce brightness to save power
2017-07-16 Add a function to get a CRC8 of the board ID
2017-07-16 Add a beacon function to send the board ID CRC
2017-07-16 Beacon the board ID instead of the hue
2017-07-16 Print board ID CRC8 on boot
2017-07-24 Expose an LED timed channel set
    Previously could only set it with default transition time.
2017-07-24 Update YABI interpolator to use error
    In same was as YABI's test code now does. This means there is no longer a minimum
    fade speed!
    [led.c]
2017-07-24 Remove fade speed restrictions from LED
2017-07-24 Fix increasing and decreasing interpolation
    [led.c]
2017-07-24 Re-enable IR send filter
2017-07-25 Add function to set wingtips/body to random color, and call when sending/RXing IR
2017-07-25 Ignore our own board ID in beacons
2017-07-26 Forward button presses to main, debouce, then beacon
2017-07-26 Remove extra 0 stage of ramp
    Now that we ignore our own beacon we don't need to cover for it with an extra
    bogus stage of the ramp.
2017-08-01 Add missing PDF of FF1.1 schematic
2017-08-04 Add first pass DigiKey compatible BOM and bad instructions
    [ff1.1-bom.csv]
2017-08-15 Fix incorrect BOM line 7
    [ff1.1-bom.csv]
2017-08-16 Updating BOM line 11
    [ff1.1-bom.csv]
2017-08-17 Fixing yet more BOM problems
    At this point all parts have been manually checked against their `Description` field (which was accurate, even if part number wasn't).
    [ff1.1-bom.csv]
2017-09-09 Add local archive of all footprints
2017-10-08 Add Kitnic Support
    [ff1.1-bom.tsv]
2017-10-08 Correct number of LEDs in Kitnic BOM
    [ff1.1-bom.tsv]
2017-10-12 Genericize BOM TSV
    [ff1.1-bom.tsv]
2017-10-12 More generic
    [ff1.1-bom.tsv]
2017-10-14 Tweak Cap
    [ff1.1-bom.tsv]
2017-10-16 Re-add DigiKey PNs
    [ff1.1-bom.tsv]
2017-10-16 Swap 10k
    [ff1.1-bom.tsv]
